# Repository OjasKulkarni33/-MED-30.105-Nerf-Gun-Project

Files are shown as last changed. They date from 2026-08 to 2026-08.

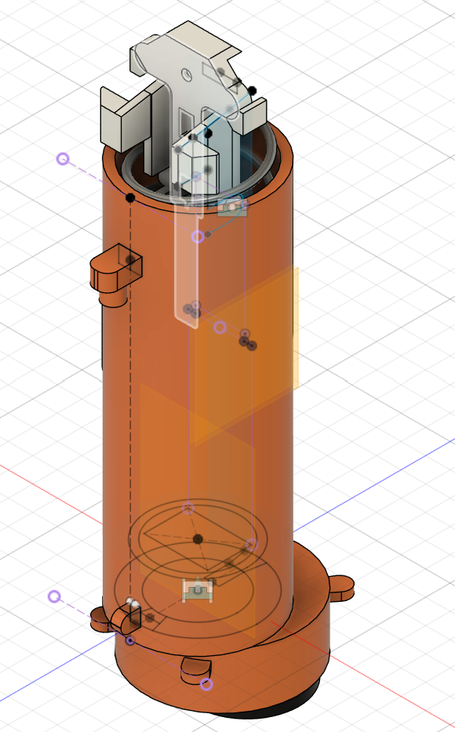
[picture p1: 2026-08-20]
Step Files/FiringSubAssy/FiringSubAssy.png

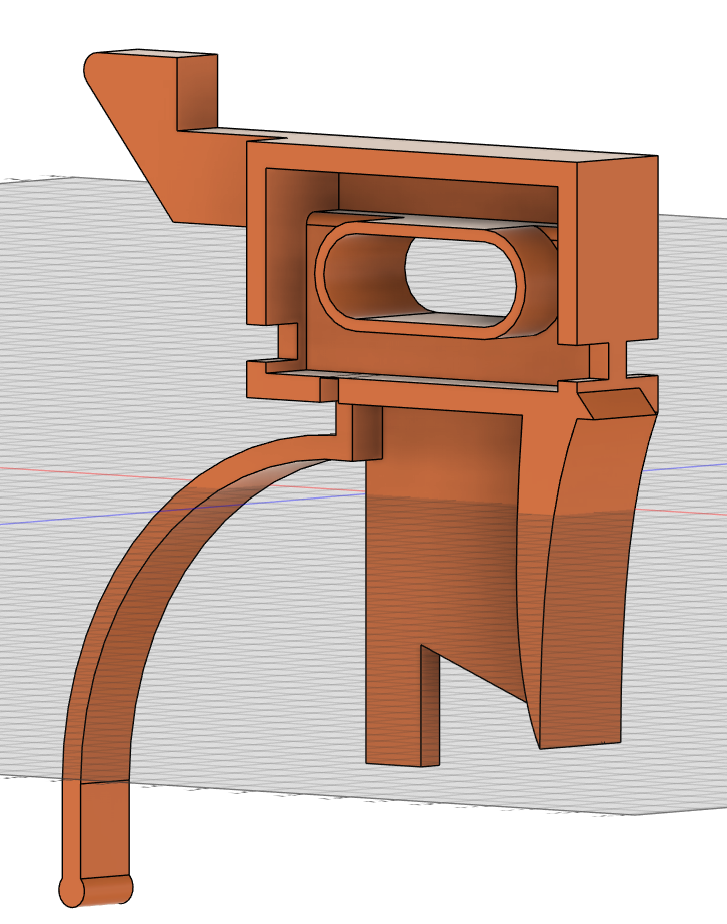
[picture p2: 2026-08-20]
Step Files/PrimingSubAssy/Trigger.png

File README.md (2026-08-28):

<br>
<p>
This project has been done as part of the module 30.105 Machine Element Design Spring 2026 with a budget of SGD 150

</p>
<p>
This repository contains report and CAD files of different sub-assemblies as well as the full assembly of Nerf Elite 2.0 Eaglepoint RD-8 Gun. 

<p>
<br>
The Nerf Gun's analysis has been broken down into 3 main Subsystems:

<br>
1. Priming
<br>
2. Firing
<br>
3. Drum Rotation
</p>

</br>

<p>
  Inside the report : 
  <br>
-> FBD of each of the components inside the subsystems are attached
  <br>
-> Forces and torques acting have been analyzed quantitatively
  <br>
-> Weakest parts have been identified with suggestions to modify them
  <br>
</p>

<br>
Project Video Link - https://youtu.be/Xe9KJtApN_8
</br>
<br>
Link to Jared Owen's video that we referenced - https://www.youtube.com/watch?v=N8JpePwvuHw
</br>
<br>
Contributors- Raina, Rey, Cheyenne 
</br>

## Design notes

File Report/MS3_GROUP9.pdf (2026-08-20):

# Milestone 3 Report

Group 09
Rey Lam Lai Yan 1007807
Raina Luke 1008004
Cheyenne Chua Yan Ting 1006974 Kulkarni Ojas Jaydeep 1008505

## Table of Contents

## Device Dissection Procedure

Nerf Gun Disassembly
Steps | Description | Tools | Pictures
1. Inspect for damages | or missing parts | | Front | Back | Left | Right

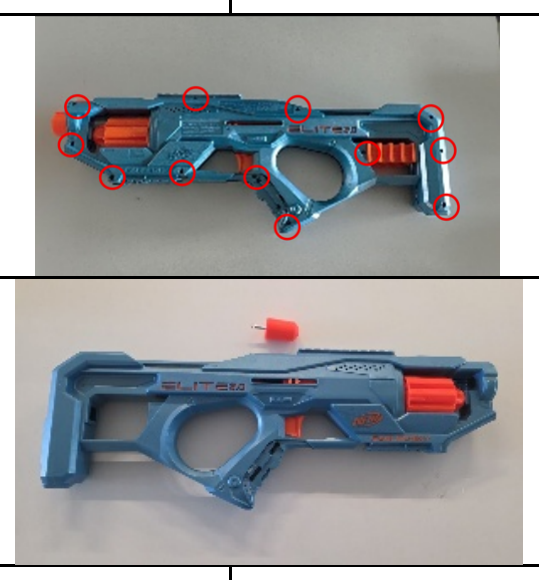
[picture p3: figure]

2 | Unscrew the 12 screws in the nerf gun circled in red | PH2 Phillips Screwdriver
3. Unscrew the knob on | the right side of the nerf gun in an anticlockwise motion
3. Remove the frame of | nerf gun
4. Remove the | detachable parts of the nerf gun

## System Overview

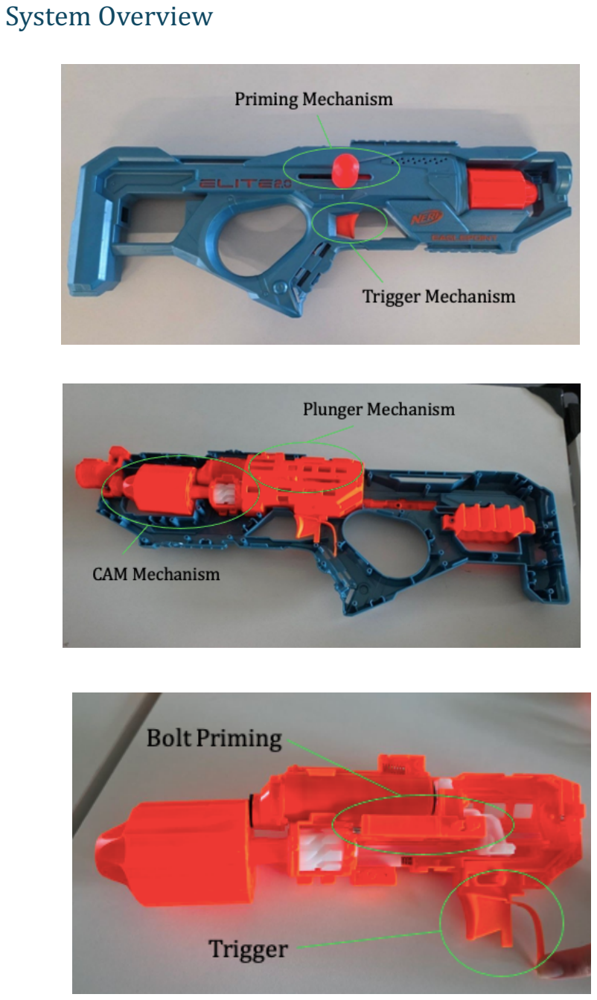
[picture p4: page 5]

## Priming Mechanism Subsystem Overview Diagram

Priming Bolt Handle

- Screwed onto the “handle link” component with a steel threaded rod
- Slides linearly along with length of the frame

Top Spring (Compressive)

- Attached onto the plunger housing to absorb the
shock from the plunger
when it Mires

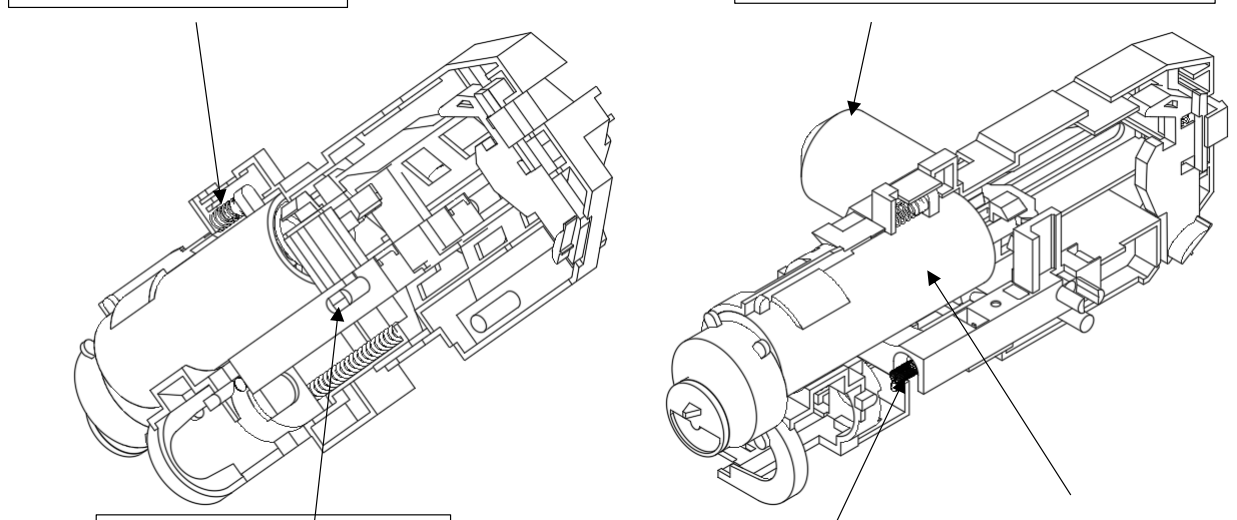
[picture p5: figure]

Helical Spring (Extension)

- Attached onto the “handle link” component to prevent lateral displacement when
priming

Handle Link

- Contains threaded grooves on either ends for the bolt handle to screw in
- Attaches onto the plunger spring housing when
priming

Plunger Housing and Plunger Spring (Compressive)

- Plunger housing houses
plunger spring (inside the housing)
- Plunger spring transfers the compressed air onto the
dart

## BOM Sheet (Priming Mechanism)

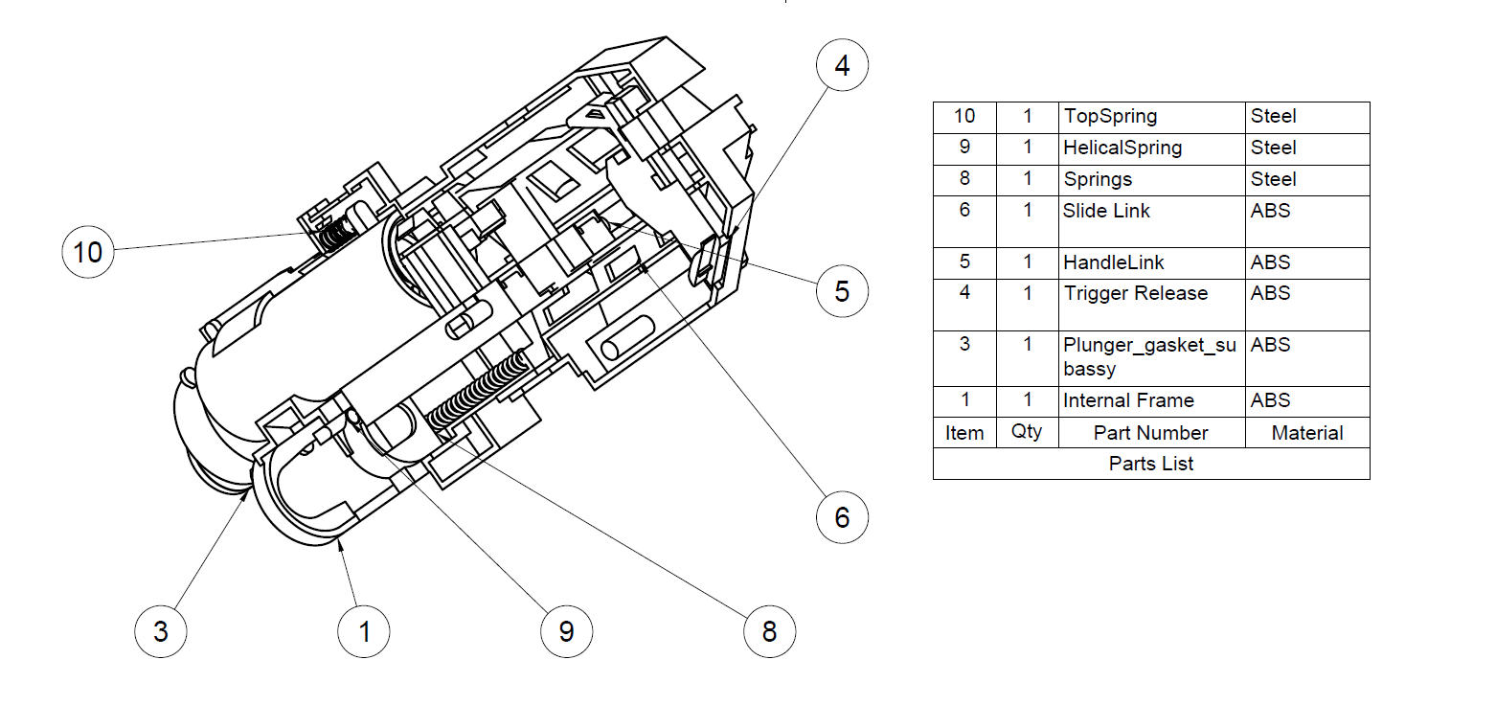
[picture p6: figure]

## 1st Weak point: Priming Bolt Shaft

## 3rd Angle Projection

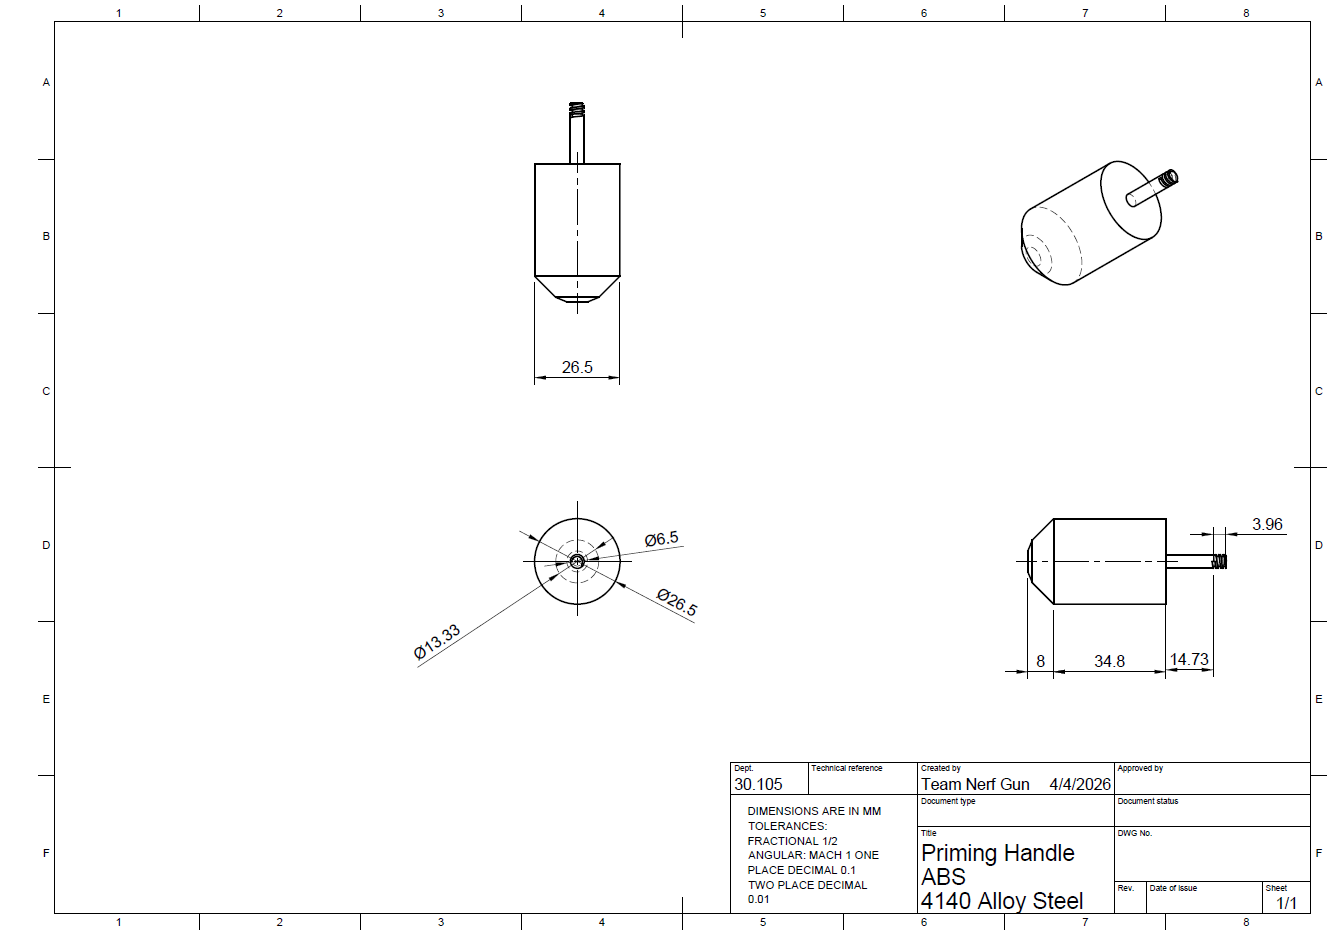
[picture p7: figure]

## FBD and Kinematic Calculations

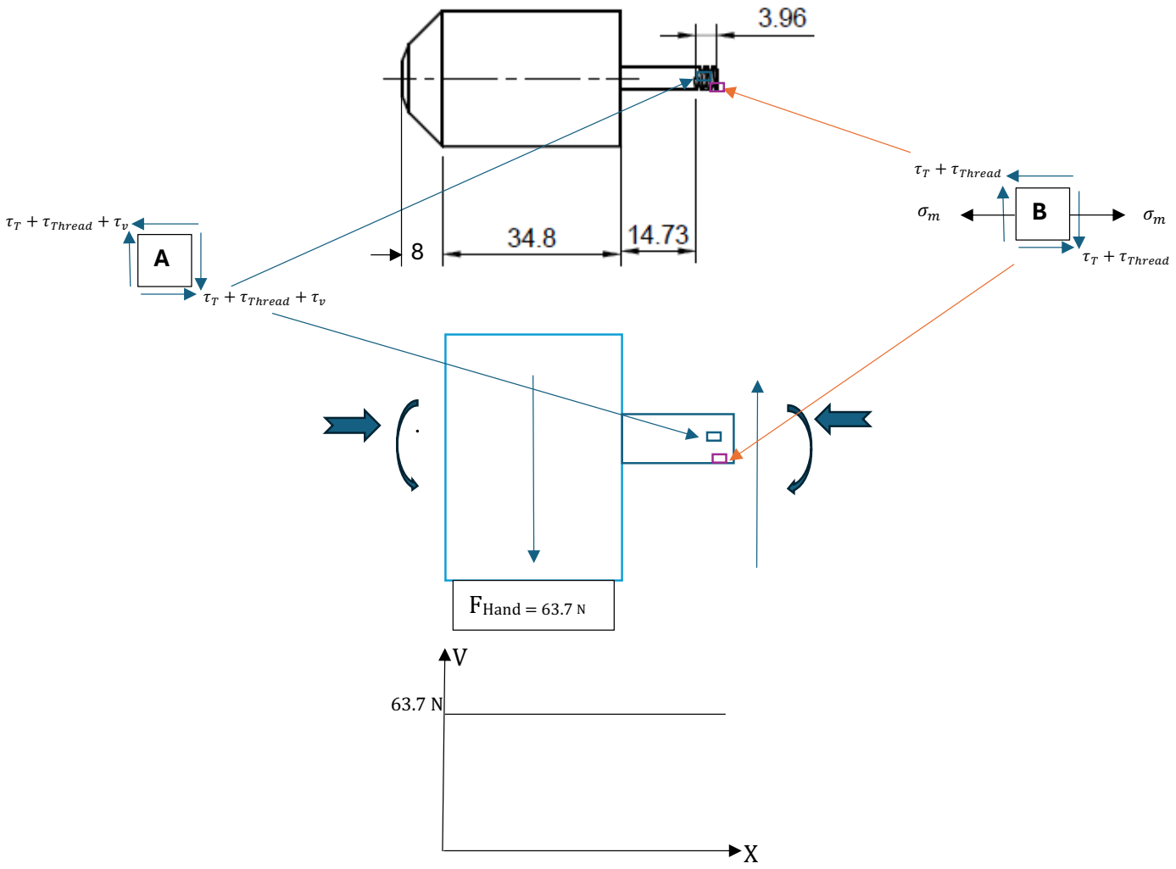
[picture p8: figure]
FHand = 63.7 N

M

3.94 N/m

X

T

1.59 N/m
X
τ! = 4V

3A = 4(63.7)
3π(2.15 × 10"#)$ = 5.84 MPa

τ% = 16T

πd# = 16(1.59)
π(4.3 × 10"#)# = 101.85 MPa

τ%&'()* = V
A+

= V πd(0.75)t = 154.4 MPa

σ, = 32M

πd# = 32(3.94)
π(4.3 × 10"#)# = 504.76 MPa

Stress at Point B is maximum and is likely to fail lirst σ-, σ$ = σ. + σ/
2 ± p(

σ. − σ/
2 )$ + τ./

$

σ. = 504.76 MPa
σ/ = 0

τ./ = τ% + τ%&'()* = 256.25

On solving we get
σ- = 612.04 MPa
σ$ = −107.2 MPa
For 4140 Alloy Steel Material, σ0 = 900, Von Misses S.F. = 1! 21"#"1"1#31##)
= 1.33

τ)5+ = ¹""1#
$

= 360 MPa

Shear Stress Safety Factor = ⁶.81!
9$%&

= 1.25

B 504.76 MPa 504.76 MPa

256.25

256.25

## 2nd Weakpoint: Plunger Spring

## 3rd Angle Projection

## FBD & Kinematic Calculations

F:);*

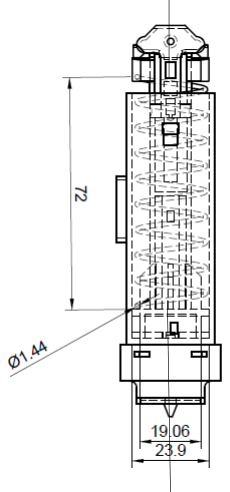
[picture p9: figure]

F<='>;?

Free Length, L@ = 70mm
Outer diameter, DA = 22.1mm Inner diameter, D> = 19.4mm Mean diameter, D = 20.75 mm
Wire diameter, d = 1.35mm
Total no. of coils, N% = N = 9 (Plain ends) Pitch, p = B'
C(

= 7.7mm

The spring is made of ASTM A401 Chrome-s, Ultimate tensile stress, SD = A(d⁵) = 2002MPa

Shear modulus, G = 78.5GPa
S;

E = 0.5SD = 810MPa

CB = 1 (axial)

CF = 0.7
C< = 0.55 (Cold − drawn)
CG = 1 (RTP)

C_R = 0.897 (90%)
S; = S;

E CBCFC<CGCH = 279.7MPa

Ultimate shear stress, SD< = 0.8 ⋅ SD = 1601.6MPa Minimum load, F,>; = 0N
Maximum load, F,). = 63.7N
Spring constant, k = *⁾F
IJ*C = 405.38 N/m

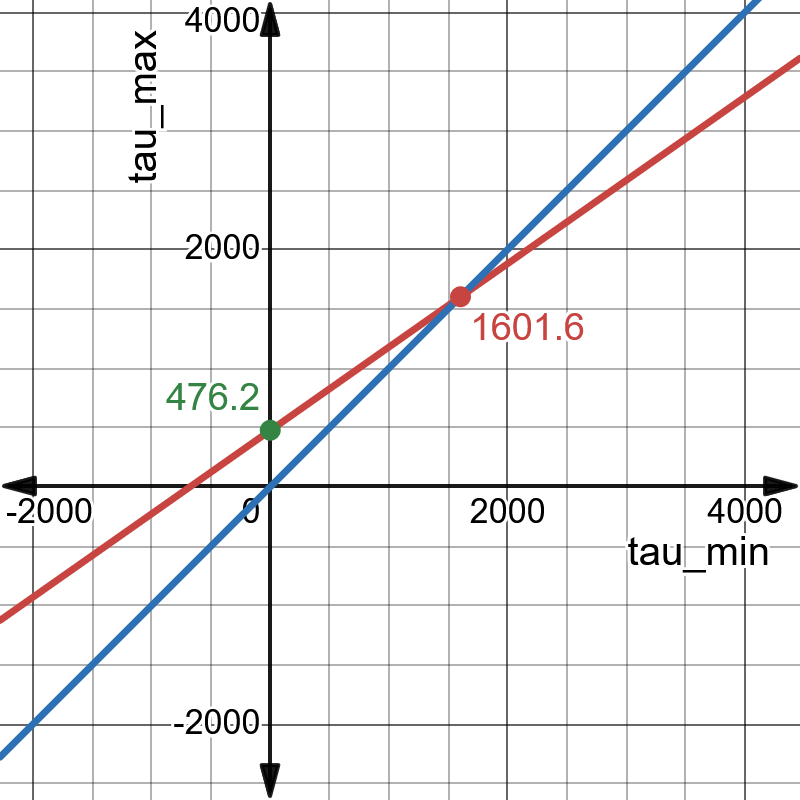
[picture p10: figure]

τ,). − τ,>; Grapℎ
SC<K, = 2SD<SC
SD< + SC

= 476.2MPa

S,). = | SD<SC<K,
SD< + (SC<K, − SD<) F,>;
F,).

= SC<K, = 476.2MPa

Spring index, C = J
* = 15.4

Wahl dynamic loading factor, KL = MN"-
MN"M

+ ⁶.O-8
N = 1.09

Measured shear force applied, F+ = 10.8N Shear spring stress, τ+ = I@+
P*# CKL = 253.3 MPa

Safety Factor, S@ = <,$-
| Q&

= 1.88

## 3rd Weak point: Extension Spring

## 3rd Angle Projection

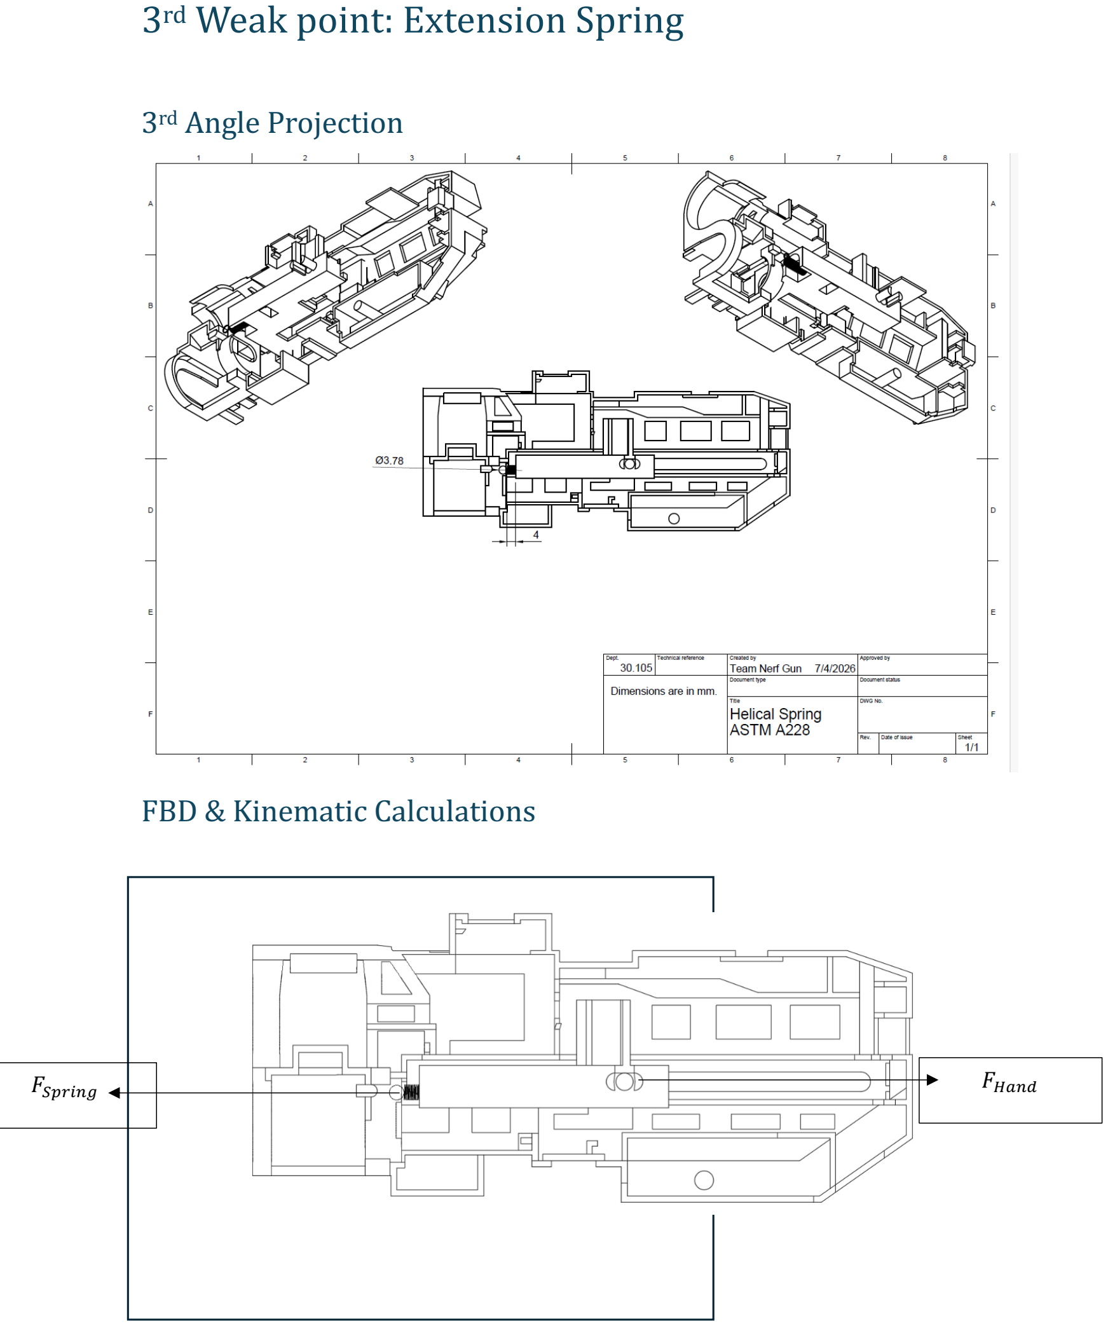
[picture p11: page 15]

## FBD & Kinematic Calculations

F<='>;? | F:);*

r- = 2.1
r# = 2.1
Wire diameter, d = 0.02mm
Mean diameter, D = 3mm
No. of Coils, N = 40
Assuming the spring is made of ASTM A228 Music wire, Shear modulus, G = 79.3 GPa
Ultimate Tensile Stress, SD = A(d⁵) = 4066.5MPa

F,>; = 0 N
Spring constant, k = *⁾F
IJ*C = 1.46 ⋅ 10"# N/m

Max extension, δ,). = 54mm
Max load, F,). = kδ,). = 7.8 ⋅ 10"8N

S;

E = 0.5 ⋅ SD = 793MPa

CB = 1 (axial)
CF = 0.7 (d < 10mm)
C< = 0.6 (Assume cold − drawn) CG = 1 (RTP)

CH = 0.897 (90% Reliability)
S; = S;

E CBCFC<CGCH = 298.75 MPa

Ultimate shear stress, SD< = 0.8 ⋅ SD = 3253.2MPa

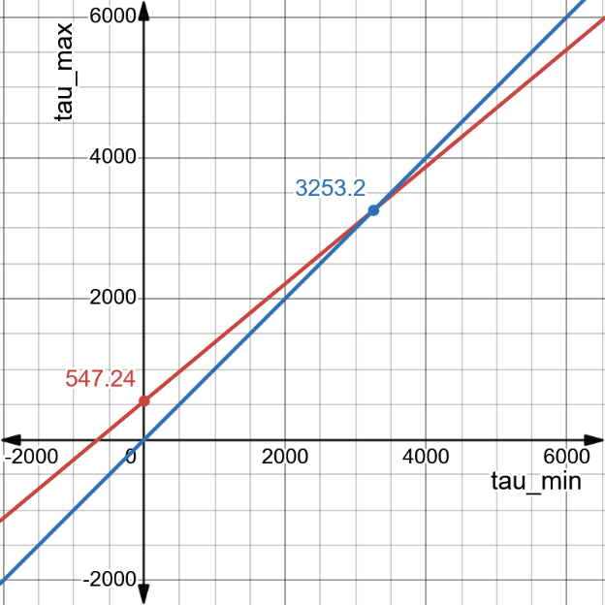
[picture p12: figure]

τ,). − τ,>;Grapℎ
SC<K, = 2SD<SC
SD< + SC

= 547.24MPa

S,). = | <.+</+0,
| <.+3(</+0,"<.+)

',12
',$-

= SC<K, = 547.24 MPa

Spring index, C = J
* = 150

Wahl dynamic loading factor, KL = MN"-
MN"M

+ ⁶.O-8
N = 1

Shear stress, τ+ = I@,$-
P*# CKL = 74.4 MPa

Safety Factor, S@ = <,$-
Q&

= 7.36

## Firing Mechanism Subsystem Overview Diagram

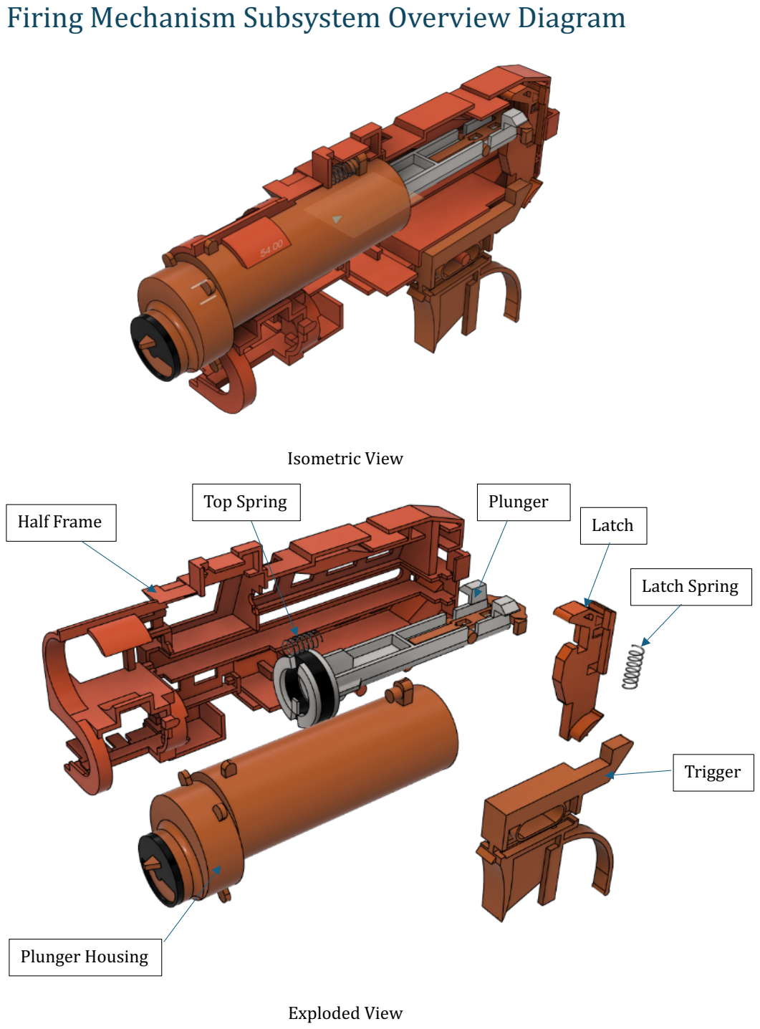
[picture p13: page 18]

Isometric View

Exploded View

Trigger

Latch

Plunger Housing

Plunger
Half Frame

Latch Spring

Top Spring

Firing Process:
1. When the blaster is primed, the plunger is pulled back and hooked on to the latch, keeping the plunger primed, and the spring within the plunger housing compressed.
2. When the trigger is pushed back by an external force, it pushes against the latch, pushing it down and compressing the spring keeping it upright
3. As the latch is pushed down, it releases the plunger, causing it to shoot forwards in its housing, releasing the necessary force to launch the bullet in the drum.
4. This release slightly pushes the plunger housing forward, which compresses the spring between the frame and the plunger housing.

## BOM Sheet (Firing Mechanism)

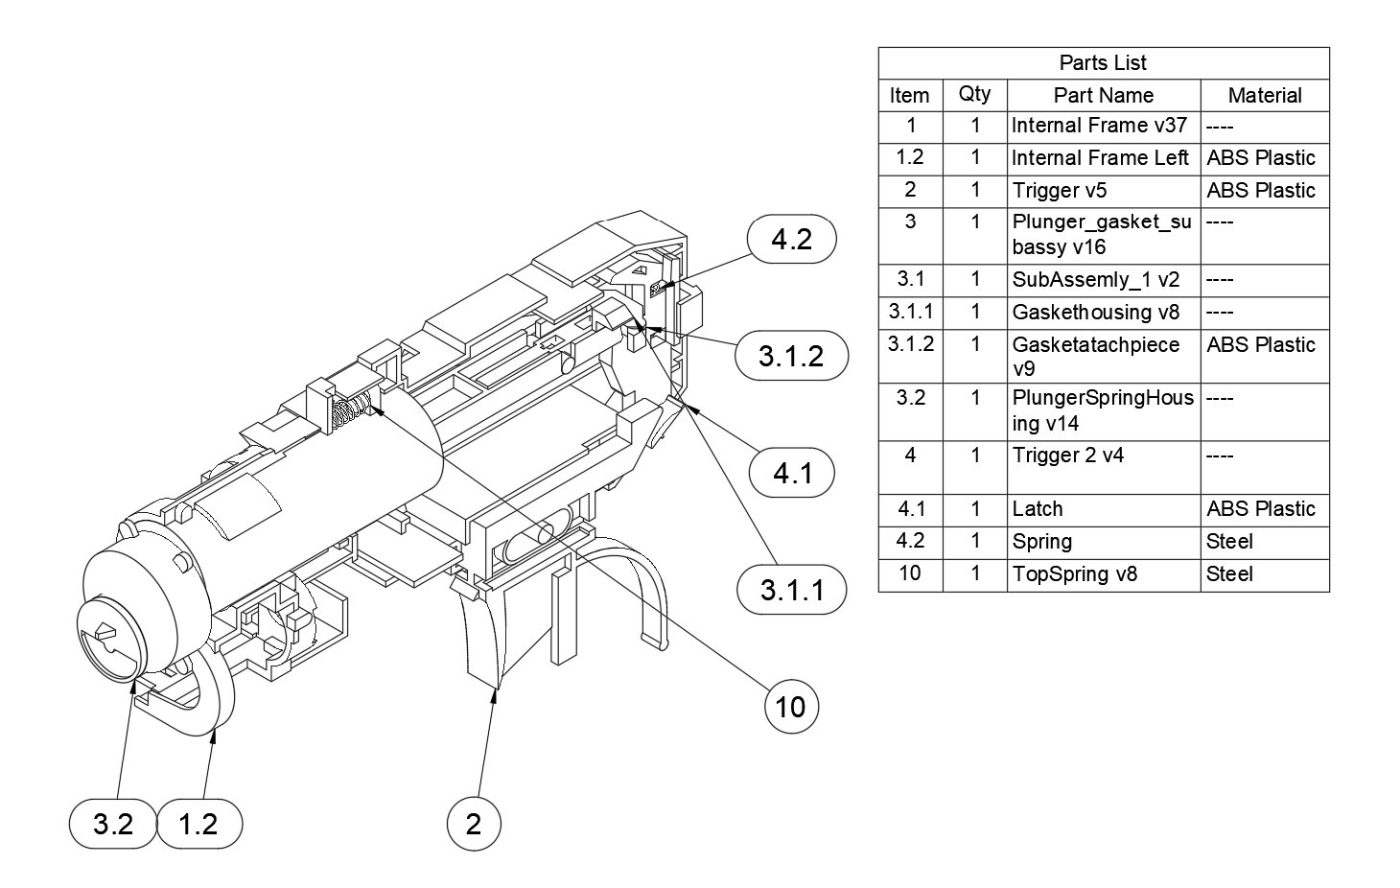
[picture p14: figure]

## 1st Weak point: Trigger Compression Spring

## 3rd Angle Projection

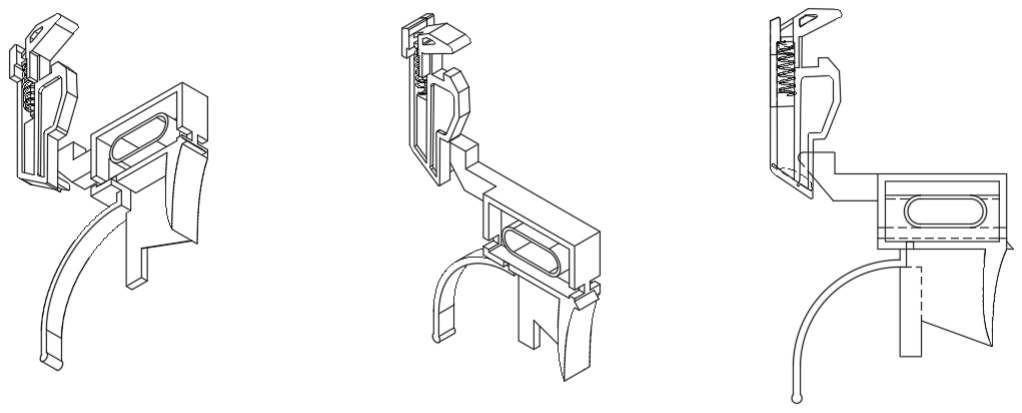
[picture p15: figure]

## FBD & Kinematic Calculations

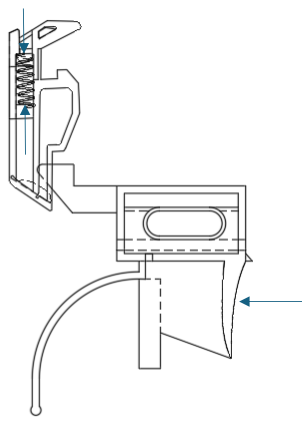
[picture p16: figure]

FBD
Assuming friction to be negligible,
Considering the spring is made from ASTM A232 wire, Coeflicient A = 1909.9 MPa
Mean diameter, D = 3.99mm
Wire diameter, d = 0.78mm

F:);*

F<

F<

Exponent b = -0.1453
Ultimate Tensile Stress, SD = A(d)⁵ = 1980.11MPa

Measured sℎear force, F+ = 4.8N
Spring Index, C = D

d = 3.99
0.78 = 5.11

Waℎl dynamic loading factor,KL = 4C − 1 4C − 4 +

0.615
C = 1.3

Shear stress, τ+ = 8F+CKL
πd$ = 153.46N

Free lengtℎ, LS = 15.8mm

Total no. coils, N% = N = 7.5 Pitcℎ, p = LS
N%

= 2.11mm

S;

E = 0.5 ⋅ SD = 990.05MPa

CB = 1(axial)
CF = 0.7(d < 10mm)
C< = 0.7(Assume cold − drawn) CG = 1(RTP)

CH = 0.814 (99% Reliability)
S; = S;

E CBCFC<CGCH = 394.89 MPa

SD< = 0.8SD = 792.04MPa

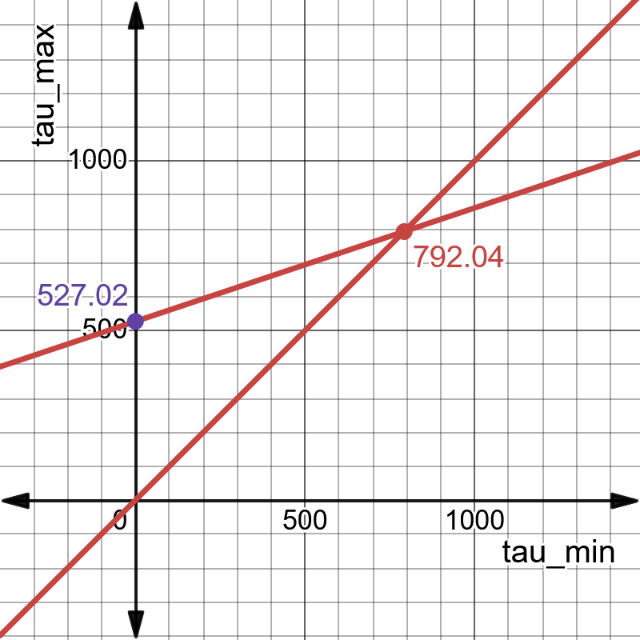
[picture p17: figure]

τ,). − τ,>; Diagram
SC<K, = 2SD<SC
SD< + SC

= 527.02MPa

Minimum load compression length, δ,>; = 0.3mm Maximum load compression length, δ,). = 10.6mm Spring constant, k = *⁾F
IJ*C = 0.12 N/m

τ,).
τ,>;

= F,).
F,>;

= δ,).
δ>

= 10.6
0.3 = 35.3
S,). = | SD< ⋅ SC<K,
SD< + (SC<K, − SD<) F,>;
F,).

= 532.06 MPa

Safety Factor, S@ = S,).
τ+

= 3.47

## 2nd Weak point: Top Spring (Fatigue Loading)

## 3rd Angle Projection

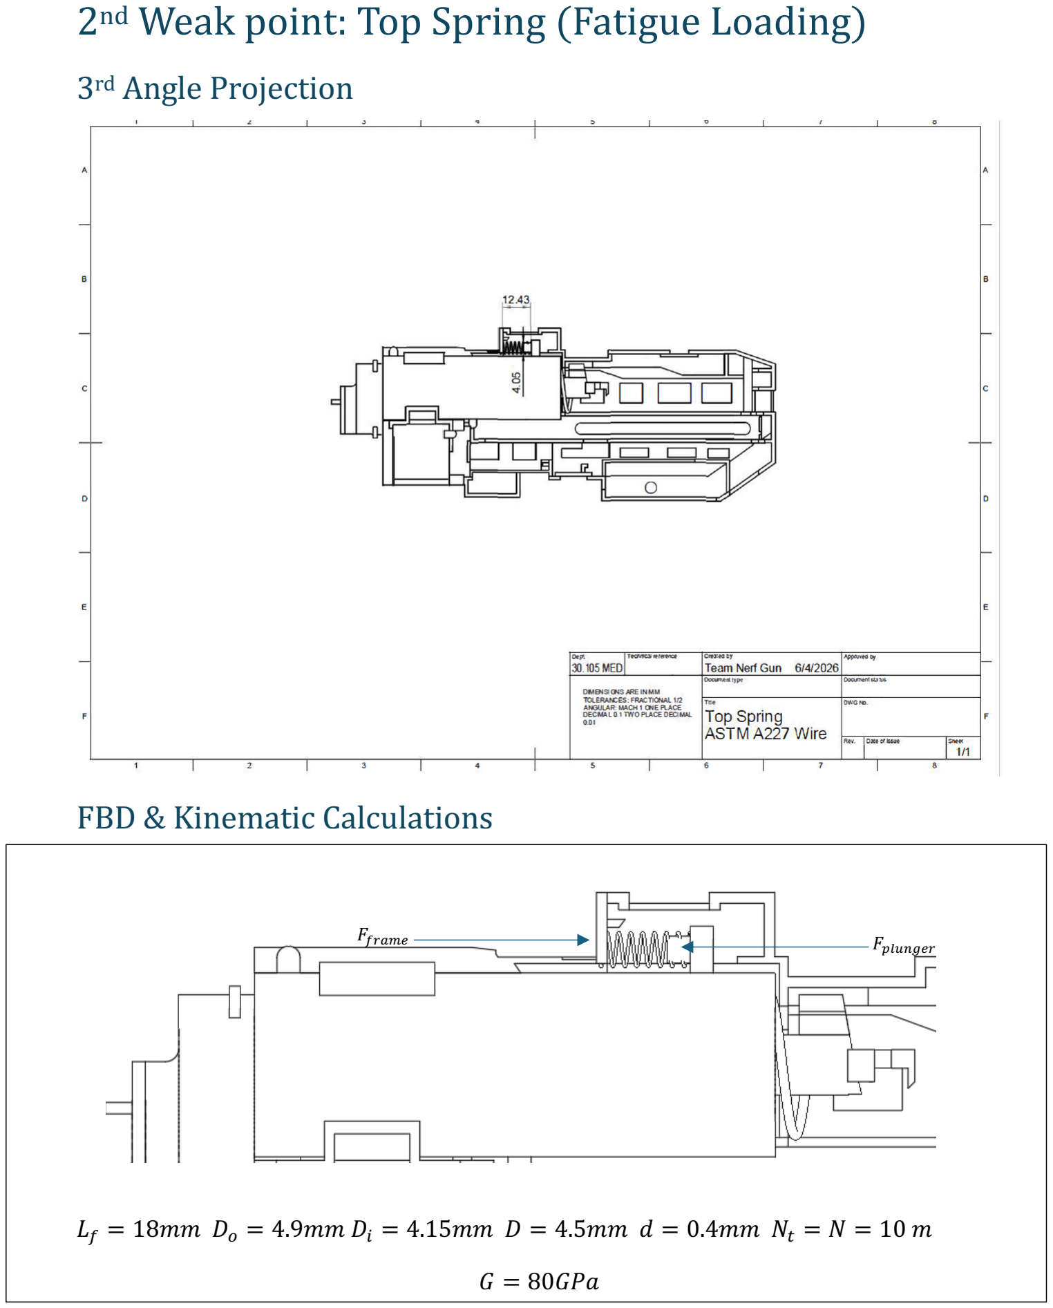
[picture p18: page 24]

## FBD & Kinematic Calculations

LS = 18mm DA = 4.9mm D> = 4.15mm D = 4.5mm d = 0.4mm N% = N = 10 m

G = 80GPa

F$%&'()*

F+*,#)

The Top Spring undergoes a fatigue compressive loading with an initial preload. Attached onto the plunger housing to absorb the shock from the plunger when it lires. k = *⁾F
IJ*C = 280.9 N/m

Considering the spring is made from ASTM A227 wire,
Coeflicient A = 1753.3 MPa
Mean diameter, D = 4.5mm
Wire diameter, d = 0.4mm
Exponent b = -0.1822
Ultimate Tensile Stress, SD = A(d)⁵ = 2071.6 MPa Spring Index, C = D

d = 4.5
0.4 = 11.25

Waℎl dynamic loading factor,KL = 4C − 1 4C − 4 +

0.615
C = 1.12

Spring Material = ASTM A22 Wire S;

E =0.5SK =0.5(2071.6) =1035.8 MPa

CB=1 (axial)
CF=0.7
C+=0.63 (cold drawn / machined) CG=1
CH=0.897
S; = S;

E CBCFC+CGCH= 409.73 MPa

SD<=0.8SD = 0.8(2071.6) =1657.2 MPa

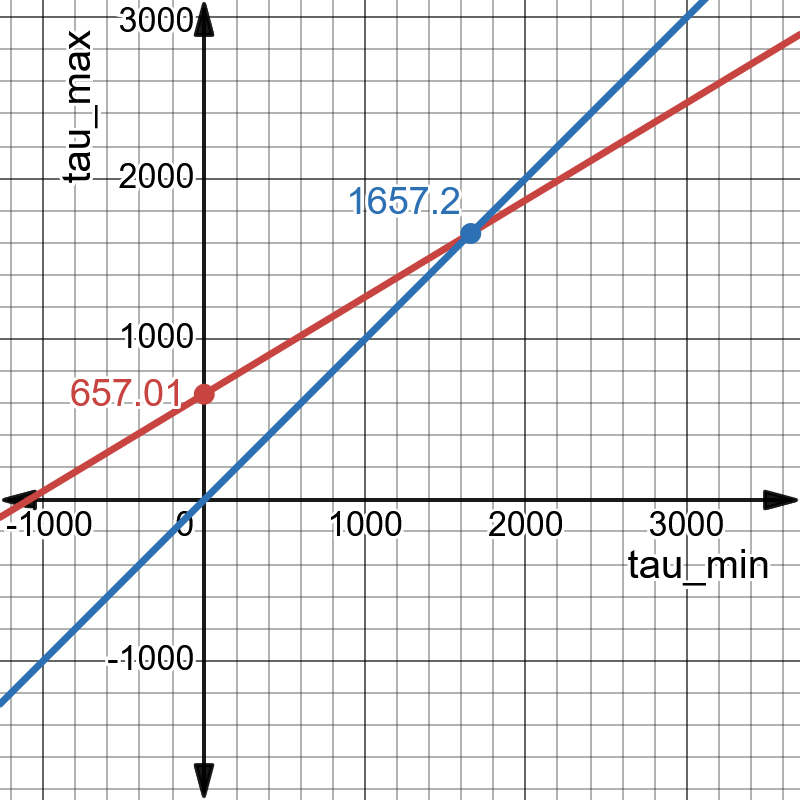
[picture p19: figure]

τ,). − τ,>; Diagram

SC<K, = $<.+</
<.+3</

= 657.01 MPa

L>;>%>)T = 12.43 ≈ 13mm | δ>;>%>)T = 18mm − 13mm = 5mm
LS>;)T = 9mm | δS>;)T = 18mm − 9mm = 9mm

F>;>%>)T = kδ>;>%>)T = 1.4N
FS>;)T = kδS>;)T = 2.5N

δU,). = δS>;)T − δ>;>%>)T = 4mm

δVT)+& = 0.1δ,). = 0.9mm
δ+ = δVT)+& + δU,). + δ>;>%>)T = 9.9mm F+ = kδ+ = 2.78N

τ,).
τ,>;

= F,).
F,>;

= δ,).
δ>

= 9
5 = 1.8

Shear stress, τ+ = 8F+CKL
πd$ | = 557.48N
S,). = | SD< ⋅ SC<K,
SD< + (SC<K, − SD<) F,>;
F,).

= 987.28 MPa

Safety Factor, S@ = S,).
τ+

= 1.77

## 3rd Weakpoint: Plunger Plain Bearing

## 3rd Angle Projection

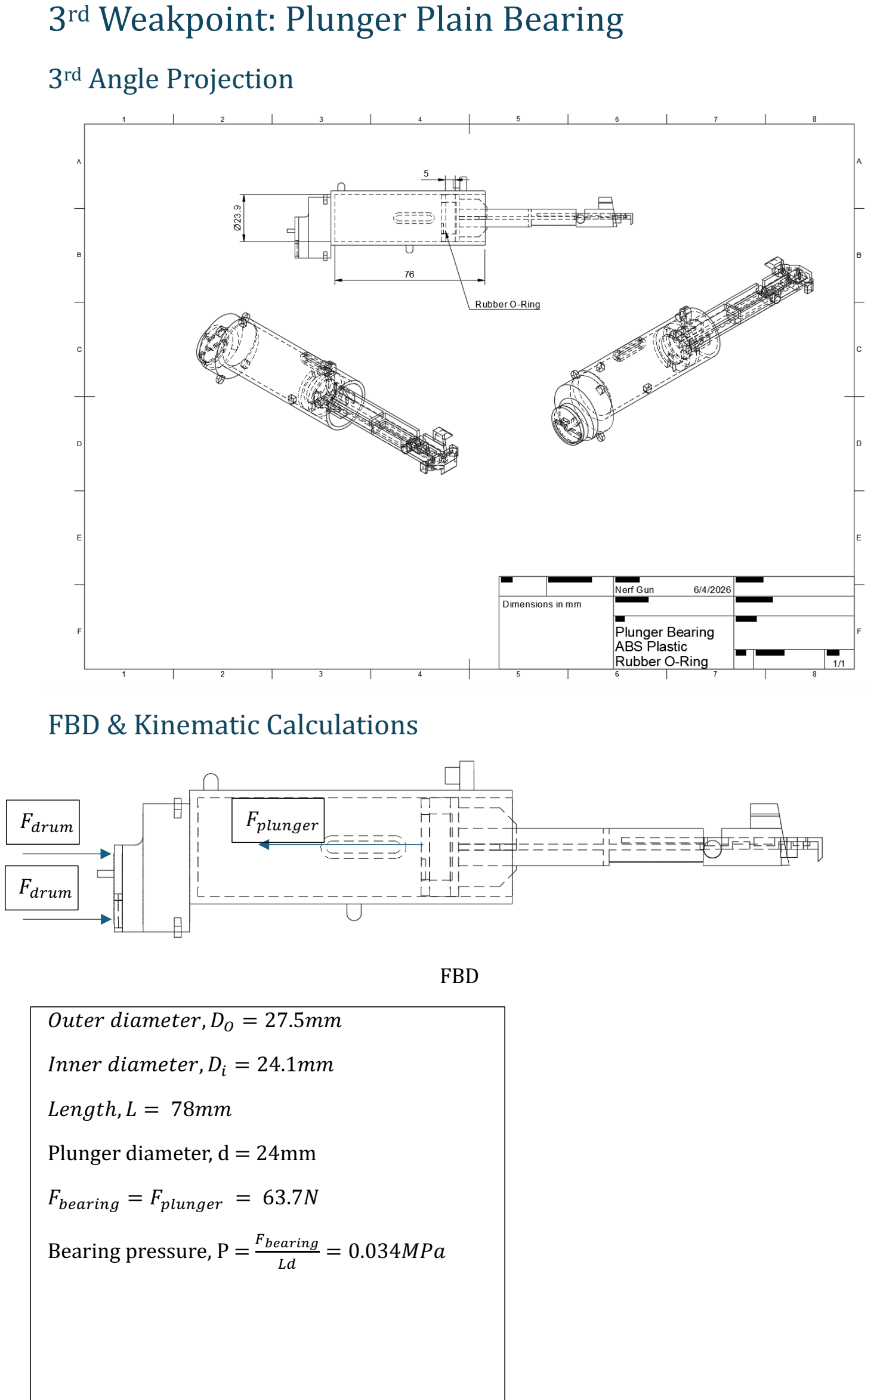
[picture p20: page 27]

## FBD & Kinematic Calculations

FBD
Outer diameter,DW = 27.5mm Inner diameter,D> = 24.1mm Lengtℎ, L = 78mm
Plunger diameter, d = 24mm

F5()'>;? = F=TK;?(' = 63.7N

Bearing pressure, P = @%3$4125
B* | = 0.034MPa
F*'K, | F=TK;?('

F*'K,

Mass of plunger, m = 18.3g Acceleration, a = @
, = 3538.8m/s$

Using v$ − u$ = 2as,

u = 0, s = 55mm

Velocity of plunger, v = √2as = 19.72 m/s PV = 0.67 MPa ⋅ m/s
Safety factor, S@ = XY61,1(
XY = 1.31

## CAM Mechanism Subsystem Overview Diagram

Process:
1. Cam rail is pulled back, moving the llat-faced follower along the surface of the cam wheel and compressing attached spring
2. Cam wheel and attached hirth joint turns anti-clockwise with the movement of the follower
3. Hirth joint transfers motion to the dart barrel, which also moves anti clockwise.
4. Cam rail is released and spring returns to natural length.

## BOM Sheet (Rotating Drum)

4

3

## Weak Point 1: Cam Follower (Rail) Spring

3rd Angle Projection

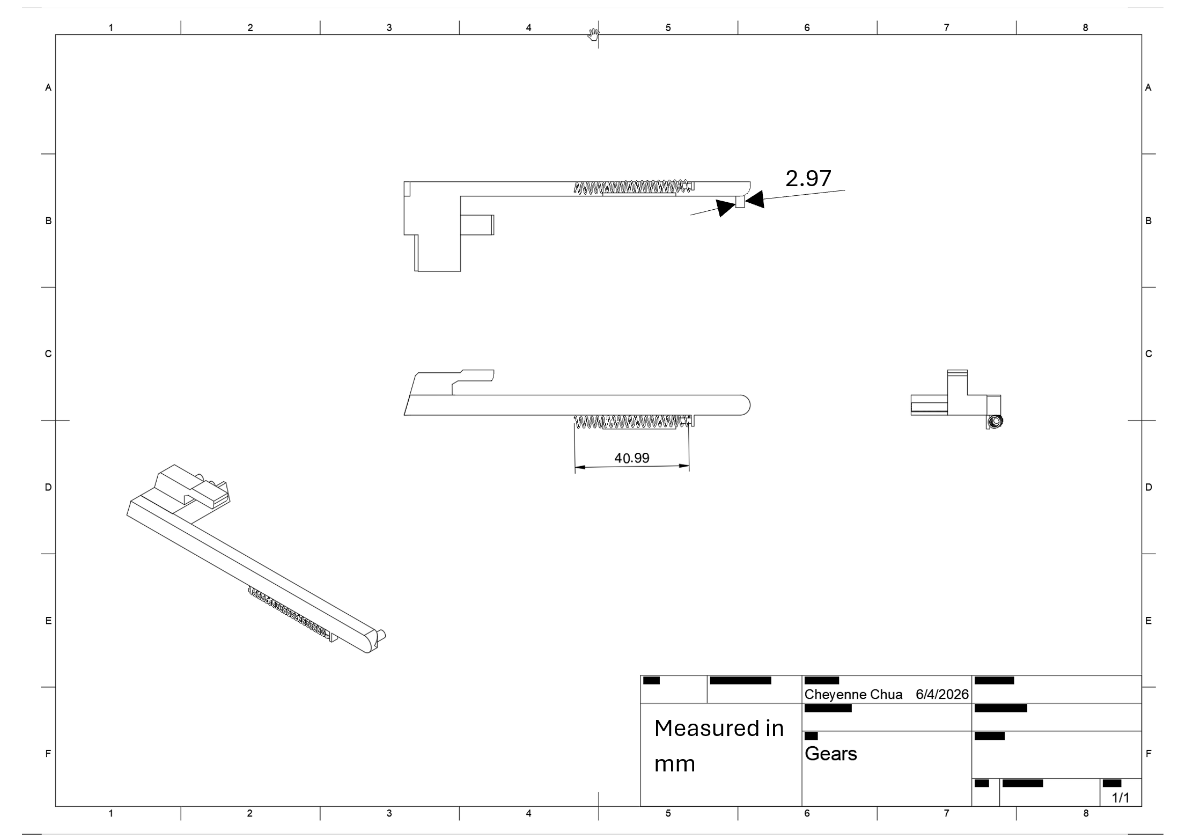
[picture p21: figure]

## FBD & Kinematic Calculations

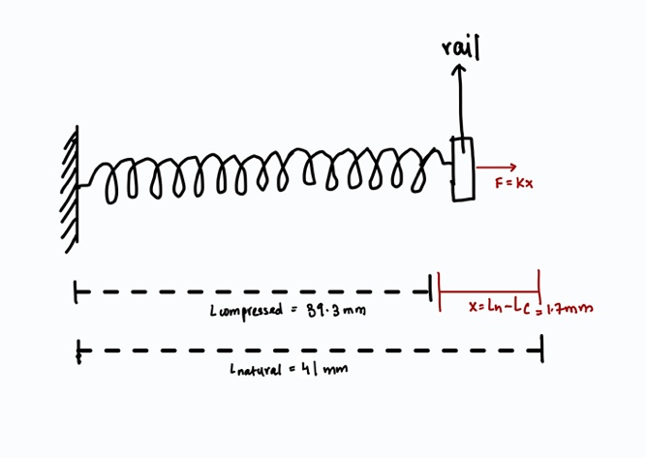
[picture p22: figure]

d = 0.46 x 10"#, D = 4.4 x 10"#, G ≈ 79×10Z, n = 21

k = *⁾F
IJ*;

k = [6.MO . -6⁷*]

)
(^Z×-6⁸)
I(M.M ` -6⁷*)*($-)

= 247.1

x = 0.017
F = kx

F = 247.1 (0.017) = 4.201N C = J
*
C =

M.M
6.MO = 9.56

KL =

MN"-
MN"M

+ ⁶.O-8
N

KL = M(Z.8O)"-
M(Z.8O)"M

+ ⁶.O-8
Z.8O = 1.1519

F,). = 4.201N (compressed)
F,>; = 0 (natural length, no preload) τ,). = 556.8
τ,>; = 0
Spring is steel, SK ≈ 1500MPa SK+ = 0.8SK = 1200 MPa
SC = 0.29(1500) = 435MPa
SC<K, = $<.+</
<.+3</

= 638.5 MPa

S,). = | <K+</&0, <.+3(</&0,"<.+)
:,12
:,$-

= 638.5 MPa

S@ = O#I.^
88O.I = 1.15

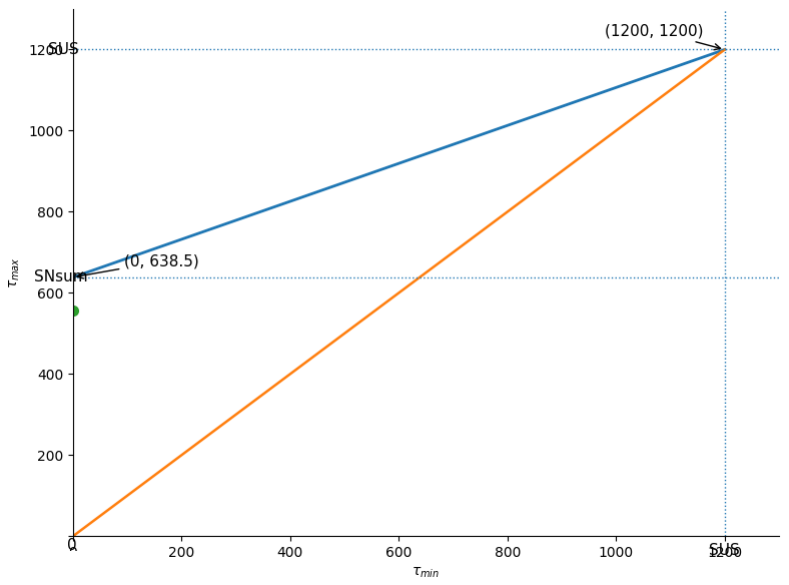
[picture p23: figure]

## 2nd Weak point: Cam Follower

## 3rd Angle Projection

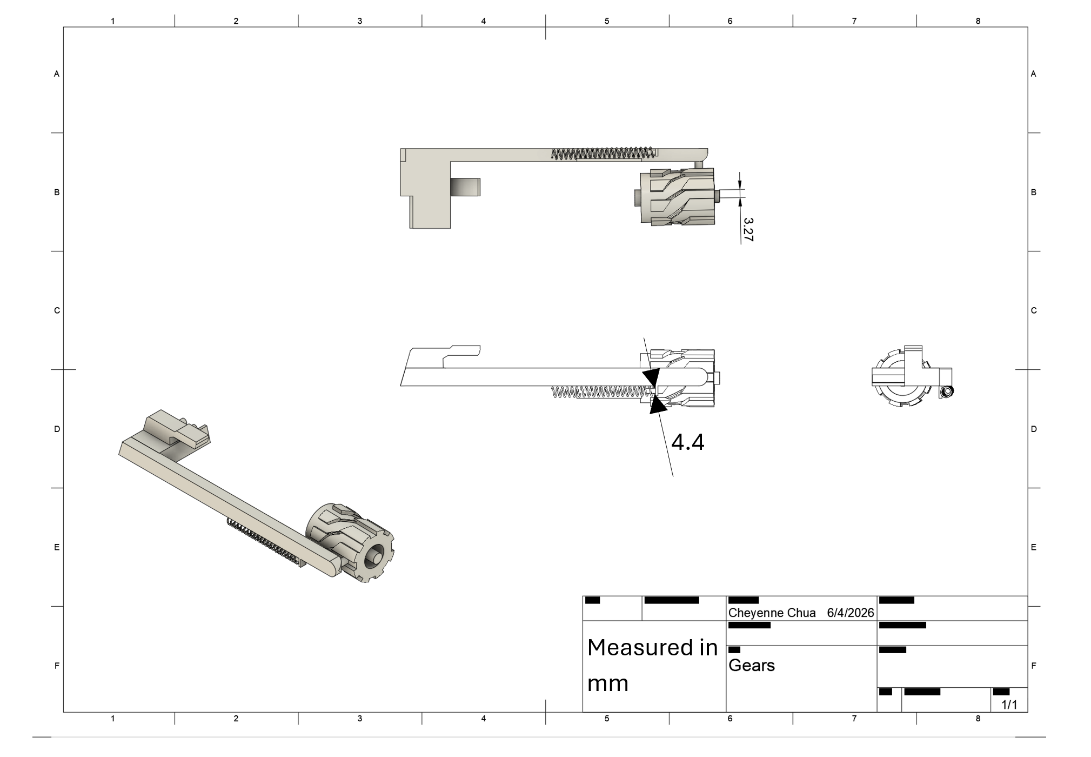
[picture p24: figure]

## FBD & Kinematic Calculations

Mass of follower: m = 7.5 x10"# kg

F)!)>T)5T(= spring

FNA;%)V% = 4.2
μ = 0.3, F;A',)T ≈ 1.5N (spring + weigℎt), rV), = 0.004m

TS'>V%>A; = μF;A',)Tr5)''(T

TS'>V%>A; = (0.3)(1.5)(0.004) = 1.8 x 10"# N

rSATTAL(' = 1.485 x 10"#m

F'(a = TS'>V%>A;
rSATTAL('

F'(a =

-.I ` -6⁷*
-.MI8 ` -6⁷* = 1.21N

S@ =

@+;4125
@43<
S@ =

M.$
-.$- = 3.47

## 3rd Weak point: Barrel and Shaft

## 3rd Angle Projection

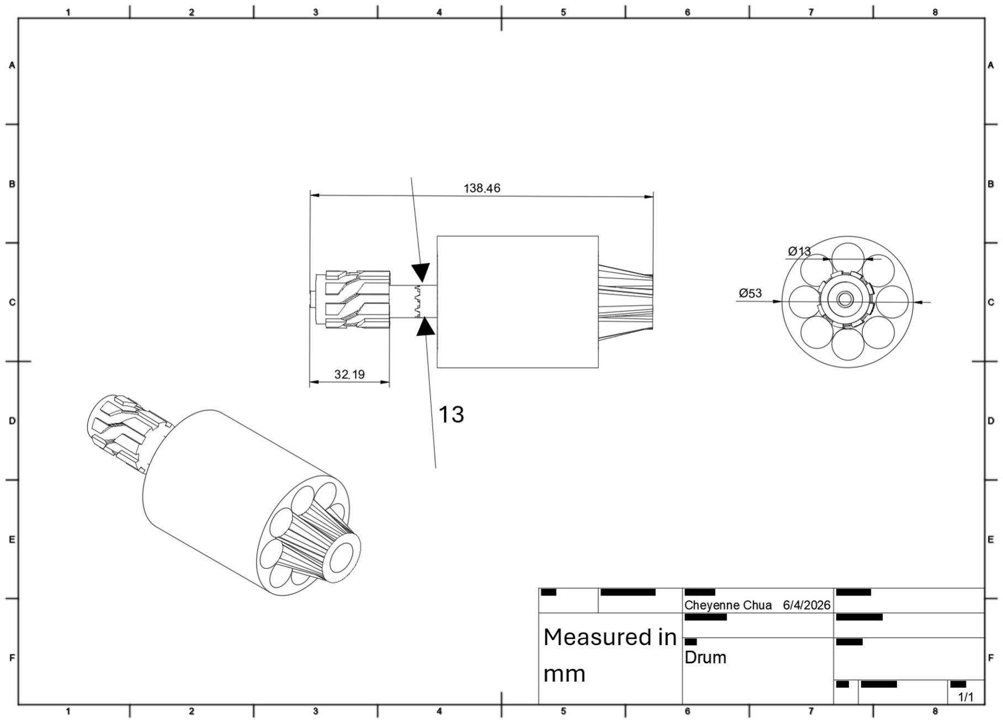
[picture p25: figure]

## FBD & Kinematic Calculations

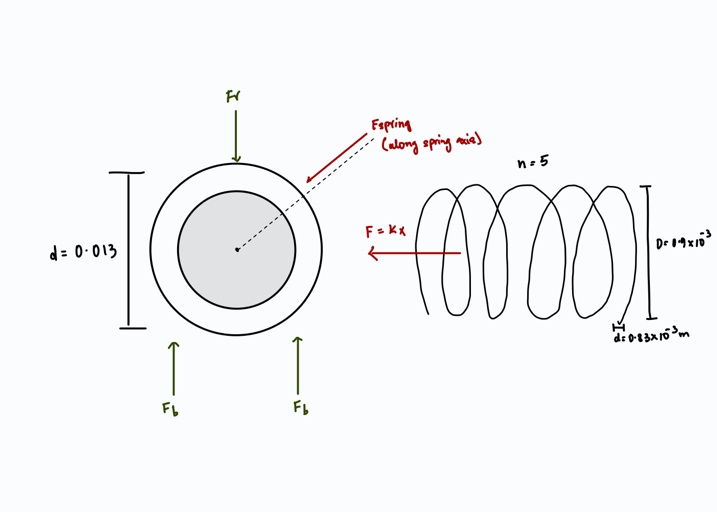
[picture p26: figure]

For the inner spring,
d = 0.83 x 10"#, D = 0.90x 10"#, G ≈ 79×10Z, n = 5

k = *⁾F
IJ*;

k = [6.I# ` -6⁷*]

)
(^Z×-6⁸)
I(6.Z ` -6⁷*)*(8)

= 1285736 N/m

Measured in mm

x = 1.4 x 10"#

F+='>;? = kx

F+='>;? = 1285736(1.4 x 10"#) = 1800N

F+='>;? = F%, θ ≈ 20°

F' = F+='>;?tanθ

F' = 1800tan20° = 655N

F5()'>;? ≈ F'
2

F5()'>;? ≈ O88-
$ ≈ 327.5N

d5()'>;? = 0.013

L = 1.9 x 10"#

P = @%3$4125
*B

P = #$^.8 (6.6-#)(-.Z . -6⁷*)
= 13.259MPa

Assuming allowable pressure of ABS: Pallowable ≈ 15MPa

S@ =

| X$66=>$%63 X

S@ =

-8
| -#.$8Z = 1.13

## Contributions

Rey: Priming & liring mechanisms
Ojas: Priming & liring mechanisms Cheyenne: Rotating barrel drum mechanism Raina: Rotating barrel drum mechanism

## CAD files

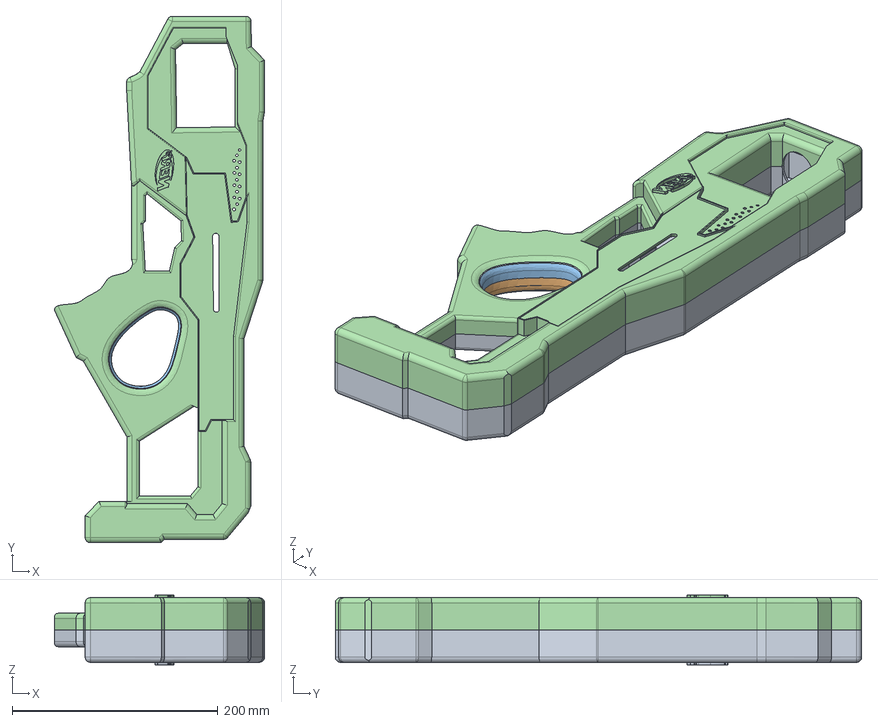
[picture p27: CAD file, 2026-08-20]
Step Files/CoverFrameSubAssy/CoverFrameAssembly.step
204.0 x 511.3 x 67.8 mm

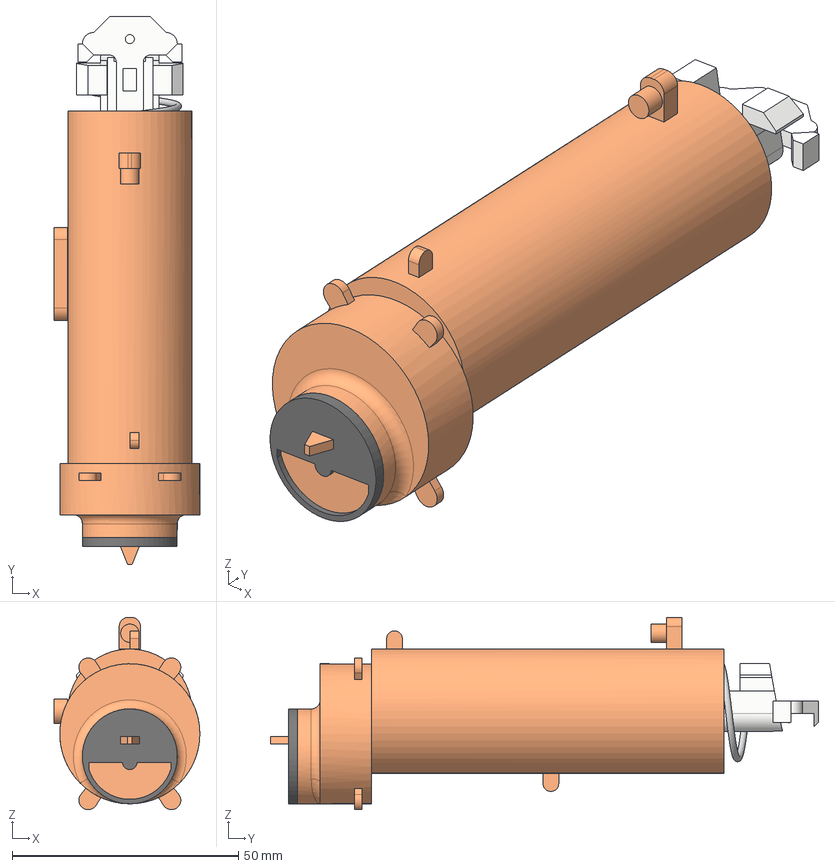
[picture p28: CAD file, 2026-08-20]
Step Files/FiringSubAssy/FiringSubAssy.step
32.2 x 121.2 x 42.5 mm
gaskethousing
gasketatachpiece
PlungerSpring
PlungerSpringHousing

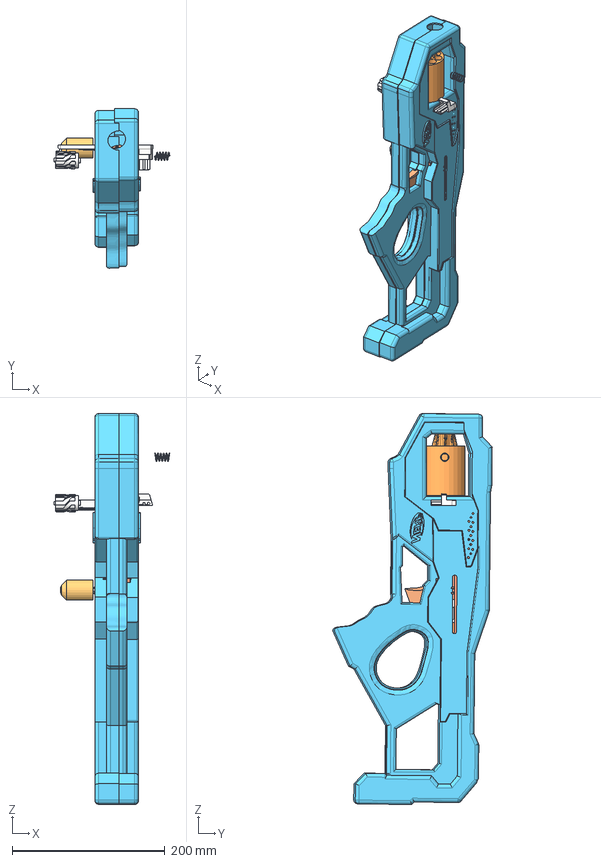
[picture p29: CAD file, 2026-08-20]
Step Files/Full Assembly/Full Assembly.step
151.4 x 208.6 x 511.4 mm
Internal Frame Right
Internal Frame Left
Bracket
Trigger
gaskethousing
gasketatachpiece
PlungerSpring
PlungerSpringHousing
Latch
Spring
HandleLink
CAM x 2
Handle x 2
HelicalSpring
TopSpring
Springs

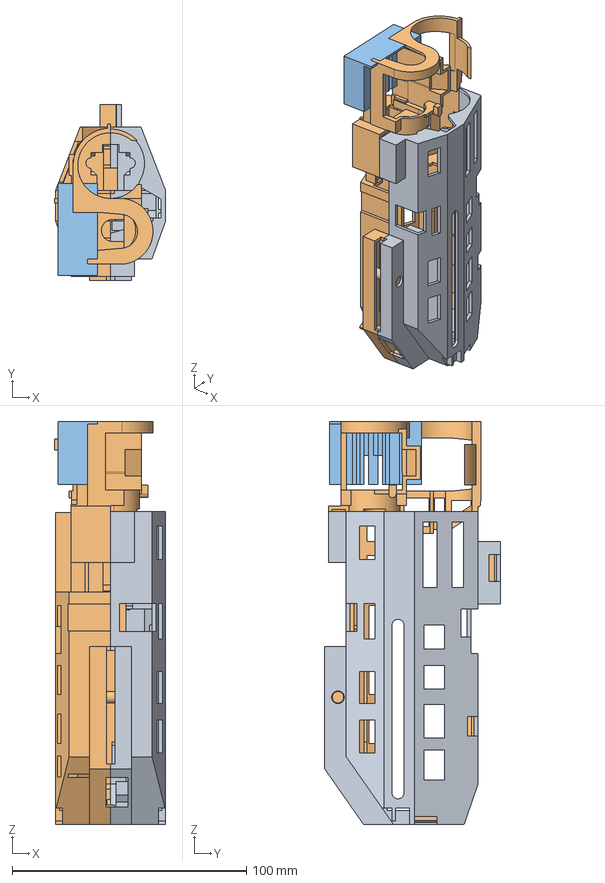
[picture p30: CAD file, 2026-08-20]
Step Files/InternalFrameSubAssy/InternalFrameSubAssy.step
47.5 x 75.0 x 171.9 mm
Internal Frame Right
Internal Frame Left
Bracket

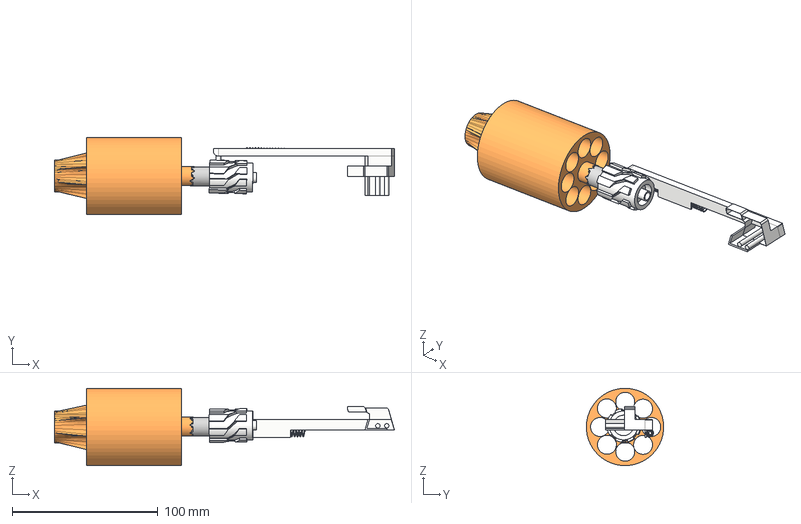
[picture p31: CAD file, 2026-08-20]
Step Files/RotatingDrumSubAssy/RotatingDrumSubAssy.step
233.1 x 53.0 x 52.9 mm
CAM
Handle

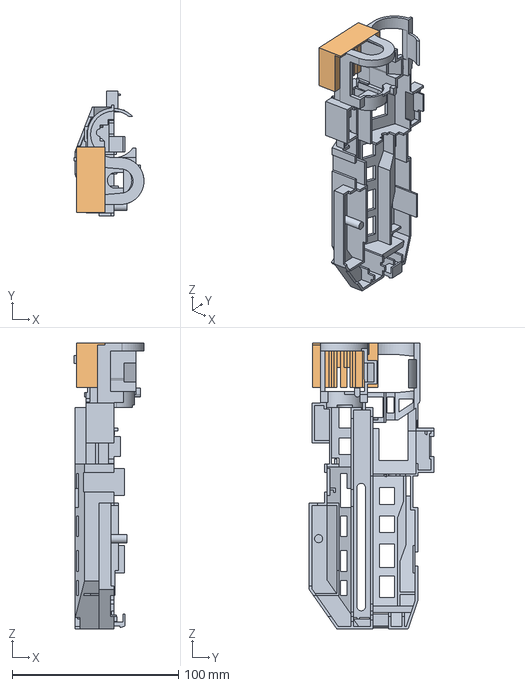
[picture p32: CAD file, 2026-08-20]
Step Files/InternalFrameSubAssy/InternalFrame[Left].step
42.1 x 75.0 x 171.9 mm
Internal Frame Left
Bracket

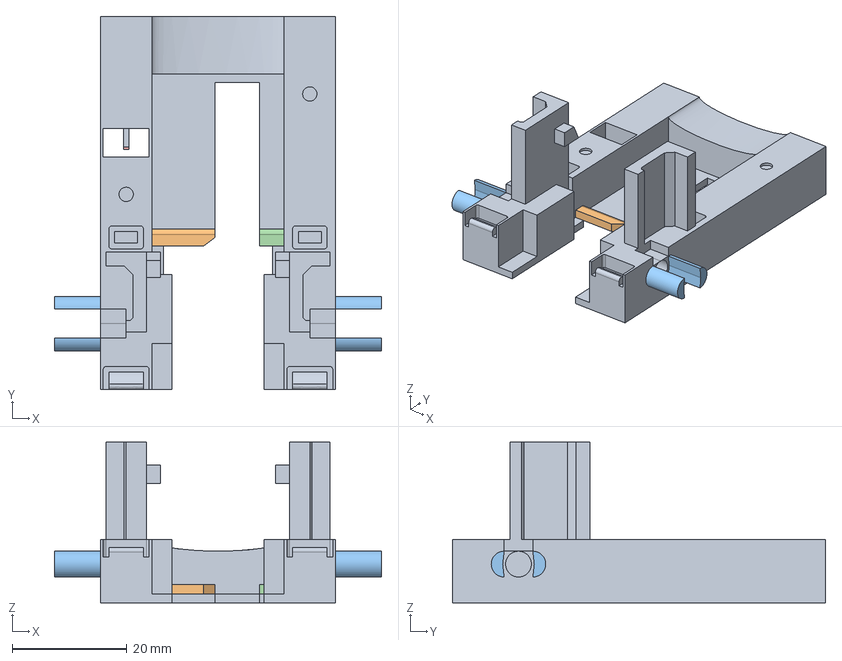
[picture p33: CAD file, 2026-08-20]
Step Files/PrimingSubAssy/HandleLink.step
57.0 x 65.0 x 28.0 mm

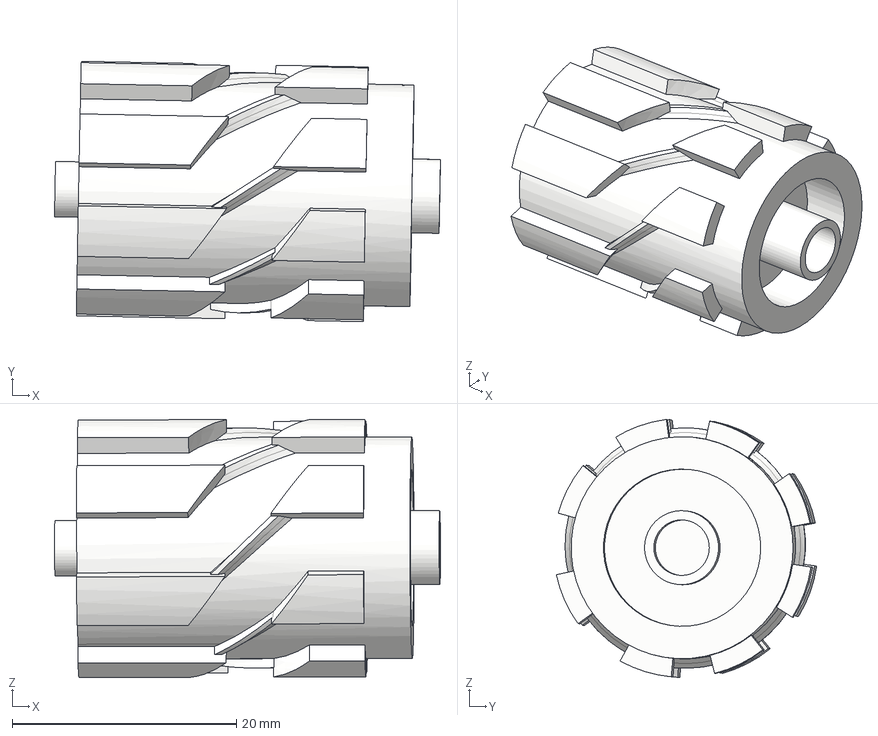
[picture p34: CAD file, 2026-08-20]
Step Files/RotatingDrumSubAssy/CAM.step
34.4 x 23.2 x 23.0 mm

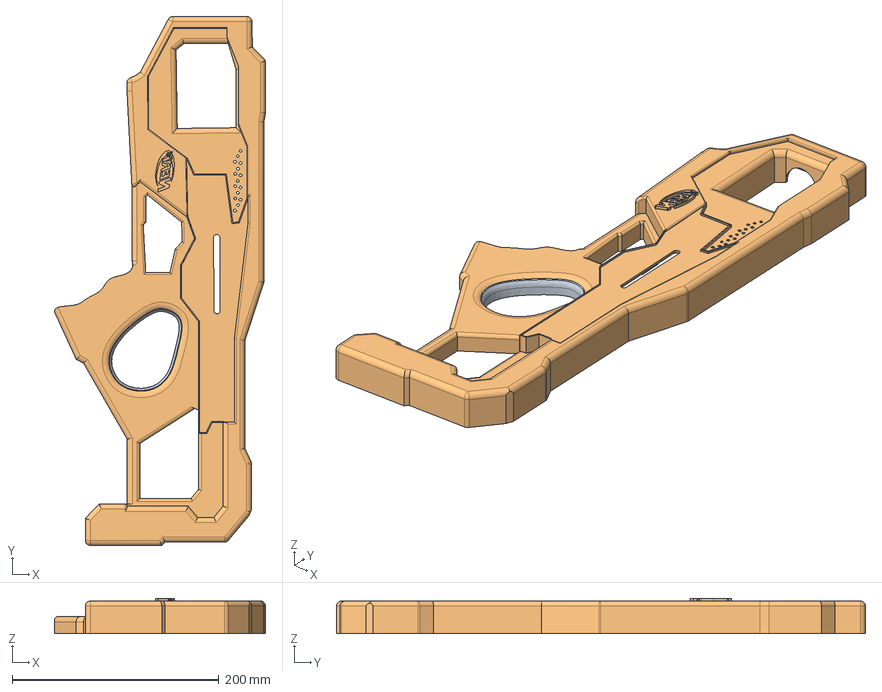
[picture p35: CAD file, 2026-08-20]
Step Files/CoverFrameSubAssy/CoverFrame_[Left].step
204.0 x 511.3 x 34.0 mm

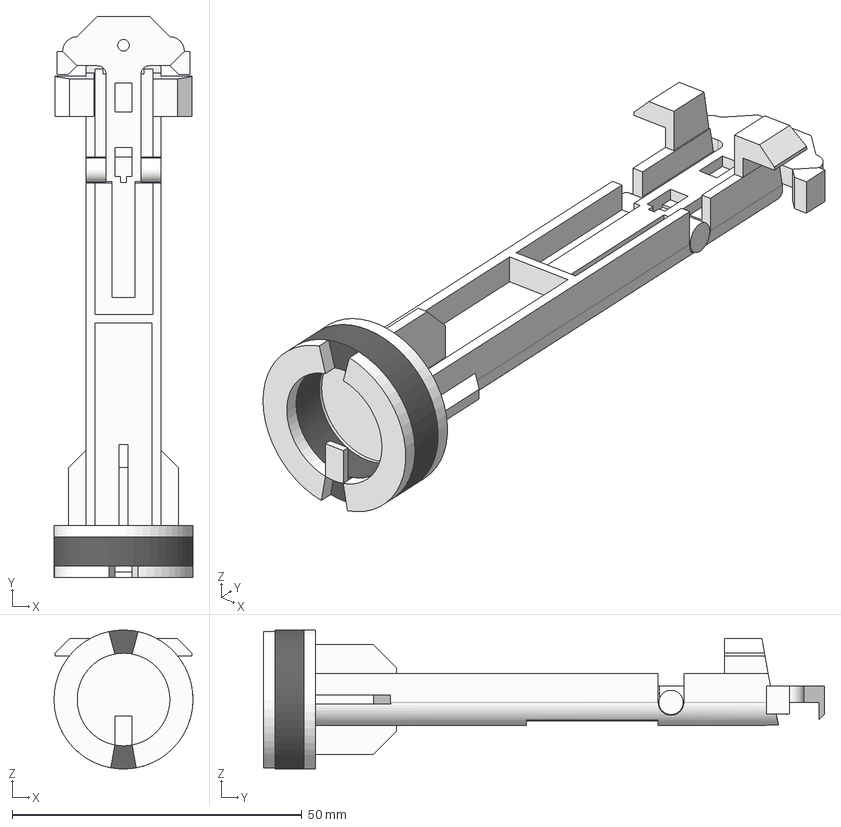
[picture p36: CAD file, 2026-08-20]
Step Files/FiringSubAssy/Piston.step
24.0 x 96.9 x 24.0 mm
gaskethousing
gasketatachpiece

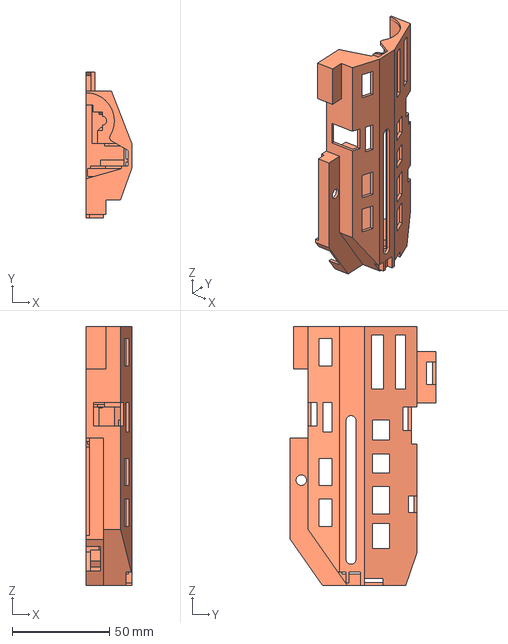
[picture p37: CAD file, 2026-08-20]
Step Files/InternalFrameSubAssy/Internal_Frame[Right].step
23.5 x 75.0 x 133.5 mm

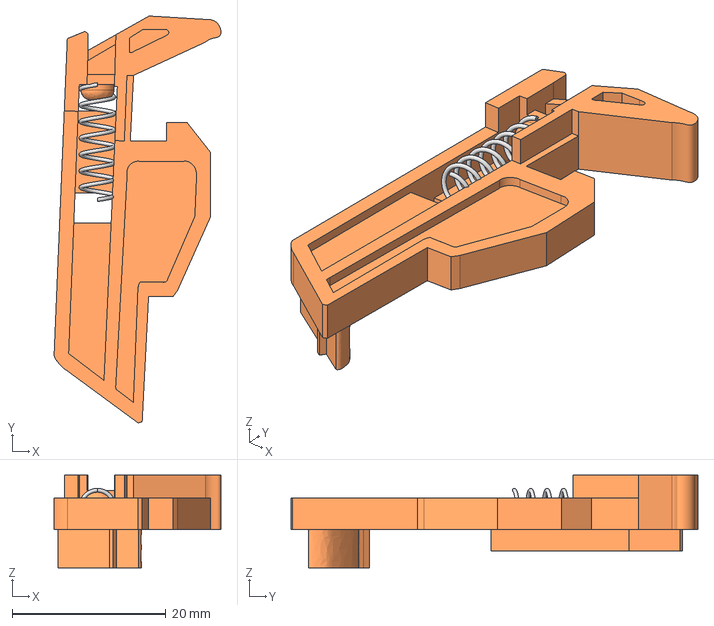
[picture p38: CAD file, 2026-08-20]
Step Files/PrimingSubAssy/TriggerLink.step
21.7 x 53.0 x 12.1 mm
Latch
Spring

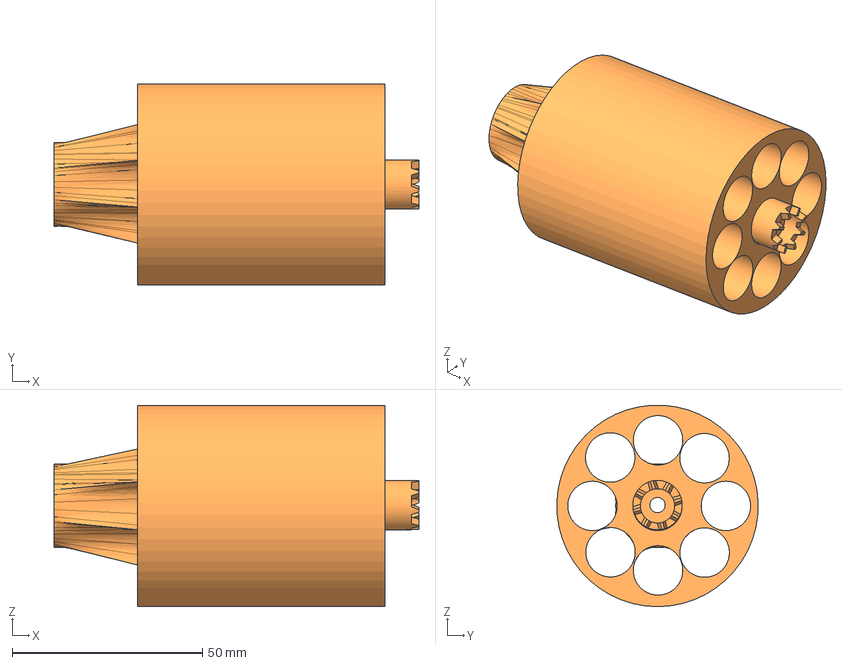
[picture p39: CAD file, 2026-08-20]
Step Files/RotatingDrumSubAssy/Drum_(Bullet Holder).step
96.0 x 53.0 x 52.9 mm

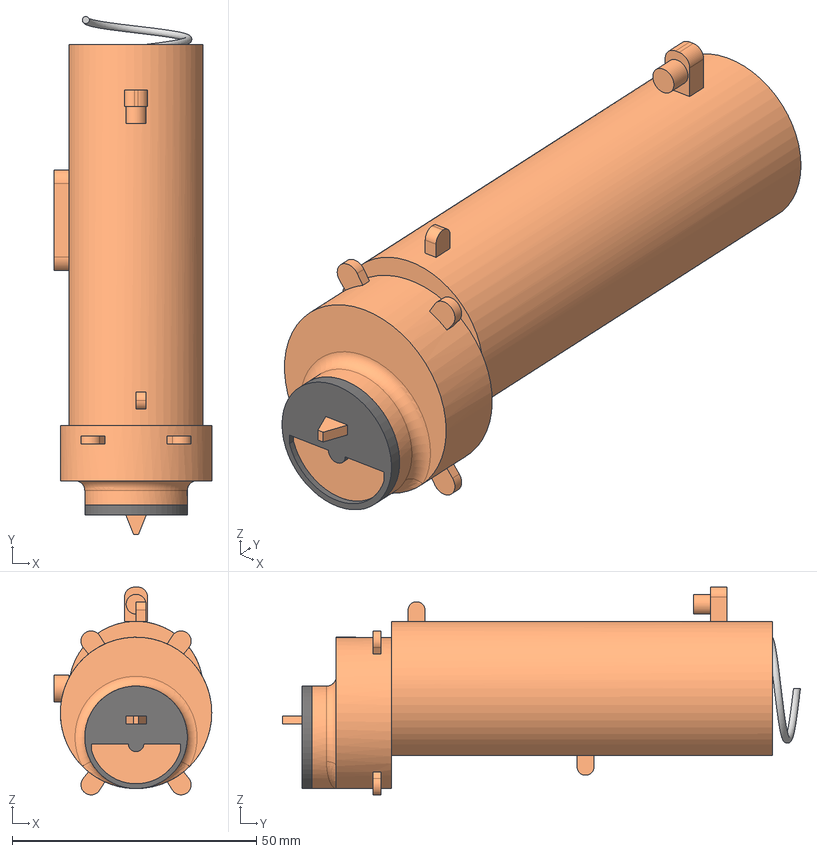
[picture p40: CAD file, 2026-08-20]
Step Files/FiringSubAssy/PistonHousing.step
32.2 x 106.0 x 42.5 mm
PlungerSpring
PlungerSpringHousing

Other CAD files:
Step Files/CoverFrameSubAssy/CoverFrame_[Right].step
Step Files/RotatingDrumSubAssy/Follower.step
Step Files/PrimingSubAssy/Trigger.step
Step Files/RotatingDrumSubAssy/ConnectionPiece.step
Step Files/Full Assembly/Full Assembly.f3z
Step Files/Full Assembly/Full Assembly.iges
Step Files/PrimingSubAssy/BoltHandle.step

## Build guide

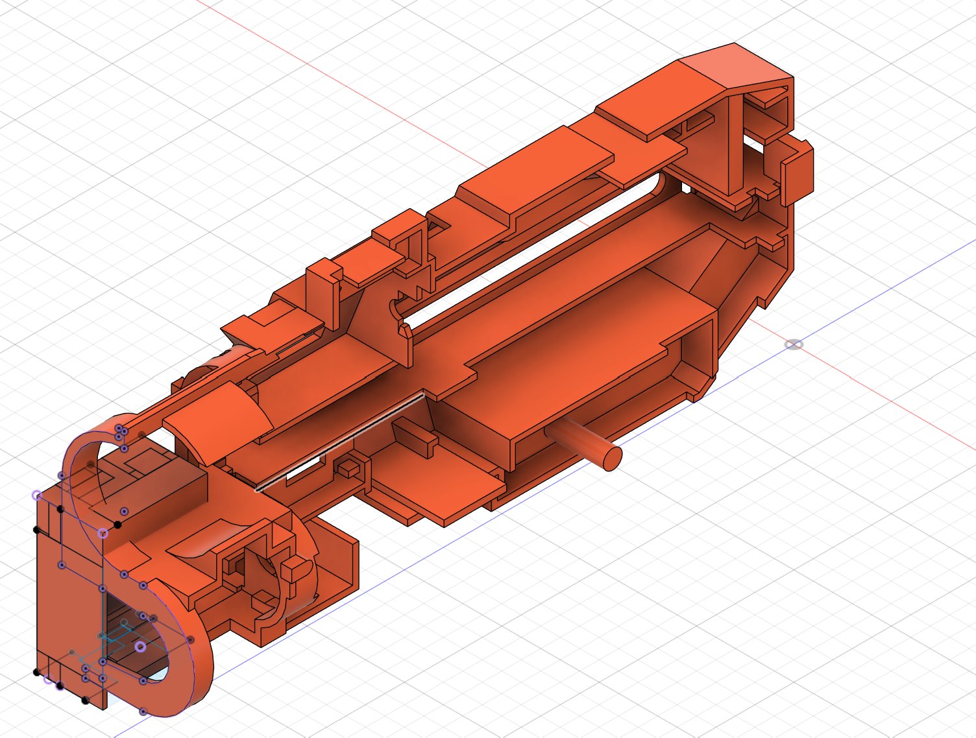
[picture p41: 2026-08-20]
Step Files/InternalFrameSubAssy/InternalFrame[Left].png

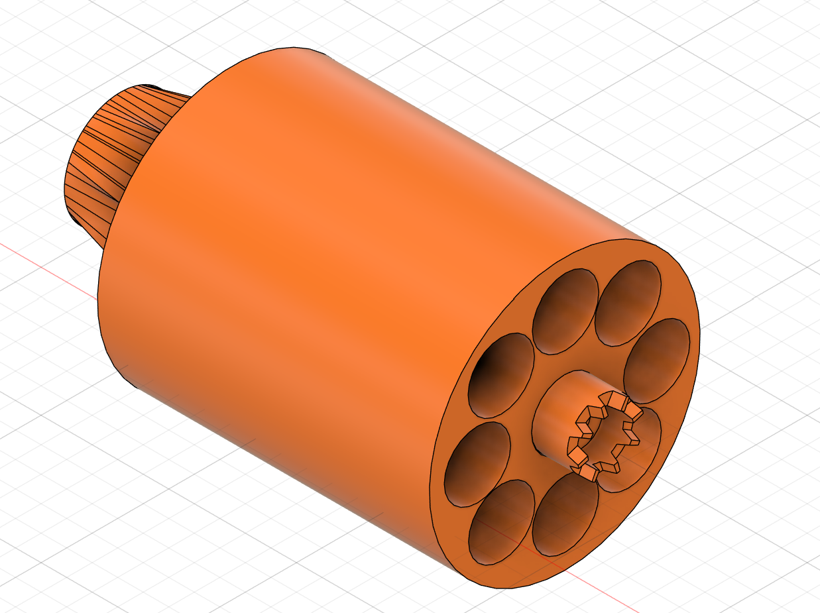
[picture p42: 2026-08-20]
Step Files/RotatingDrumSubAssy/Drum_(Bullet Holder).png

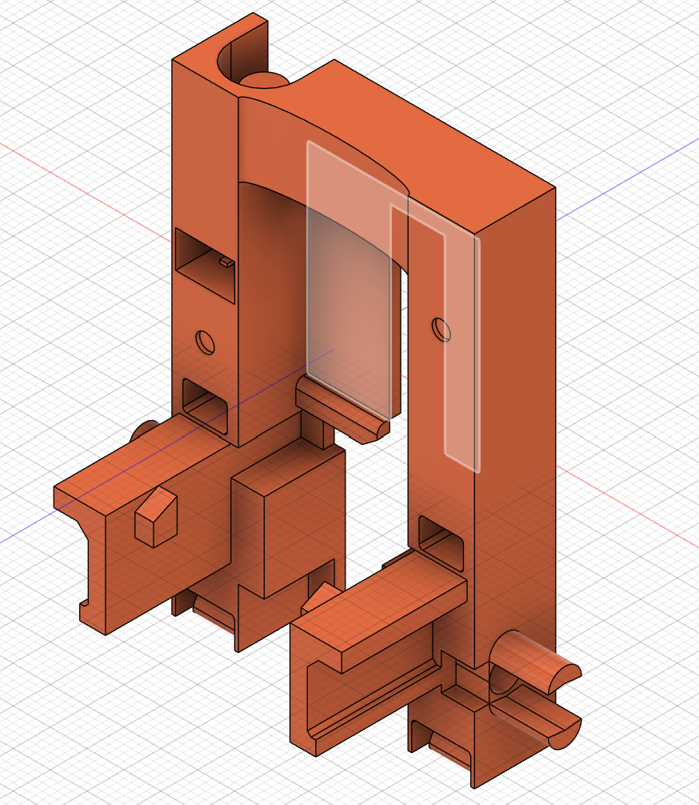
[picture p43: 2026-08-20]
Step Files/PrimingSubAssy/PrimingHandle.png

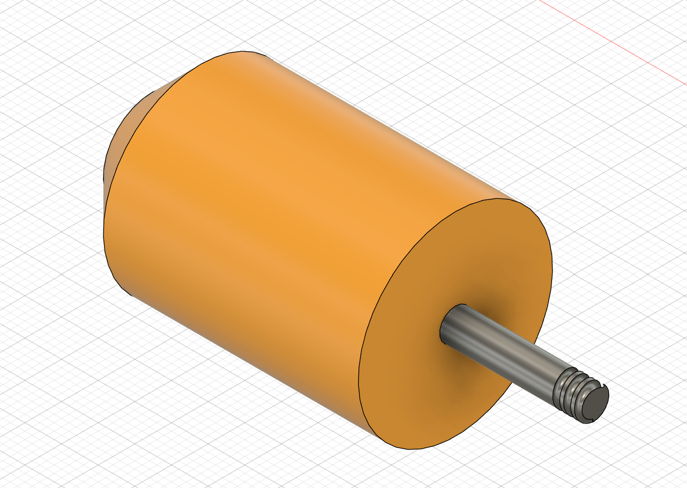
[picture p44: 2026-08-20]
Step Files/PrimingSubAssy/BoltHandle.png
